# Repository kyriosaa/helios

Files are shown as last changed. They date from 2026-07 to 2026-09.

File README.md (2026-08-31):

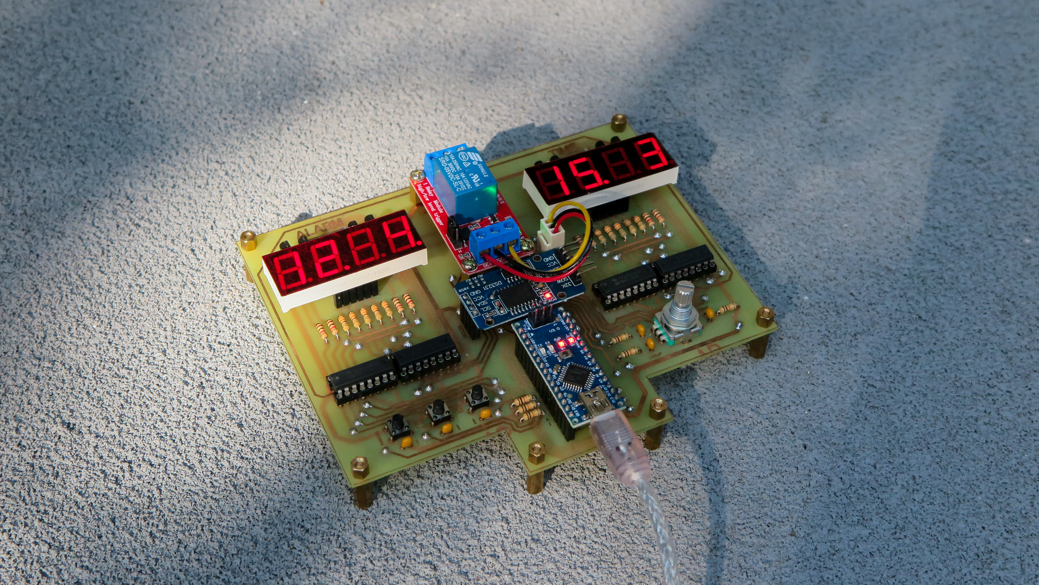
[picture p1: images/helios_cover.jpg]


# Helios


[]()



A real-time lamp controller for my room. Keeps the time (even when unplugged) and flips a relay once the clock and alarm values match. 

My room doesn't have windows so I created this device to automatically turn on my bedside lamp and put myself into fight or flight every morning to help me wake up in time for work/school.

🎥 [Demo Video](https://youtu.be/W-aWS8Oxe-Q?si=ozM3OOpzgYfn5PJq) 🎥

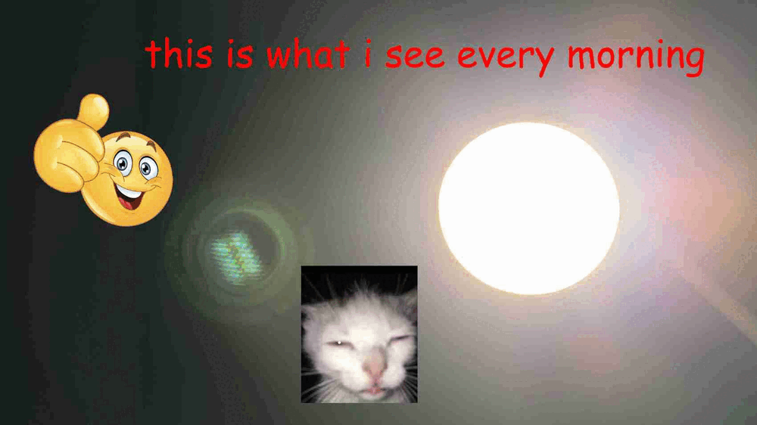
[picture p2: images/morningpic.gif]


| Sections |
| -------- |
| [Design](#design) |
| [Features](#features) |
| [Hardware](#hardware) |
| [PCB Design](#pcb-design) |
| [Schematic](#schematic) |
| [Images](#images) |

## Design

Some notes on why the board is built the way it is.

### A DS3231 instead of the MCU's own timer
The RTC has its own coin-cell backup, so the clock survives a power outage or being moved to another room. Keeping time on the MCU would mean re-setting the clock every time the device lost power, which is exactly the kind of small annoyance that would make me stop using it.

---

### Discrete multiplexing over a dedicated driver
A MAX7219 or TM1637 would have done this with fewer parts and less code. I used two 74HC595s for the segments and a 74HC138 plus PNP high-side drivers per display because I to practice building the multiplexing myself instead of buying it in a chip.

---

### A polled encoder, not an interrupt 
Every input has a 10k resistor and a 100nF capacitor on it to filter out switch bounce. The tradeoff to this is that signals now fade between HIGH and LOW over about a millisecond instead of snapping. During that fade, the Arduino can't really tell which one it's looking at, so a little noise makes it read HIGH-LOW-HIGH-LOW a few times before settling. An interrupt on `ENC_CLK` (D2) would count every one of those HIGH-LOW flips, so one click of the encoder knob would add 3 or 4 counts. However, reading the pin in the `loop()` function only ever sees the value after it settles, which solves the issue.

---

### Two board versions 
The 2-layer version is meant to be manually etched. But I know most people dont have an etching machine, so the 4-layer version is for anyone who doesn't have an etching setup and would rather send it to a manufacturer (I'm also experimenting with curved traces on the 4-layer version).

## Features

| Feature | Description |
| --- | --- |
| **24/7 Timekeeping** | A coin battery supports the DS3231, so pulling the plug doesn't require a manual time recalibration |
| **Dual Displays** | Separate 7-segment displays for the current time and alarm |
| **Manual Override** | One button forces the lamp on and disarms the alarm. The armed state is shown by a decimal point on the alarm display |
| **System ON/OFF** | Pressing the encoder blanks the displays and cuts the relay |
| **Multiplexed Digits** | Two 74HC595s (daisy-chained) drive segments, 74HC138s + PNP high-side drivers select digits |

## Hardware

| Ref | Qty | Part | Role |
| --- | --- | --- | --- |
| **A1** | 1 | Arduino Nano v3.x | MCU, socketed so it can be swapped without desoldering |
| **U1, U4** | 2 | 74HC595 | Daisy-chained shift registers driving the segment lines |
| **U2, U5** | 2 | 74HC138 | 3-to-8 decoders selecting which digit is lit |
| **U3, U6** | 2 | CA56-12EWA | Common-anode 4-digit 7-segment displays (time and alarm) |
| **Q1–Q8** | 8 | BC557 (PNP) | High-side drivers sourcing current into the selected digit |
| **SW1** | 1 | ALPS EC11E rotary encoder w/ switch | Sets values; pressing it toggles the system on/off |
| **SW2–SW4** | 3 | 6mm tactile push button | Mode, set, and manual lamp override |
| **J1** | 1 | JST-XH 1x03 | Relay / lamp output |
| **J2** | 1 | 1x04 pin socket | DS3231 RTC module (VCC, GND, SDA, SCL) |
| **R1–R6** | 6 | 10k | Pull-ups on the encoder and buttons |
| **R7–R10, R27–R30** | 8 | 1k | Base resistors for the PNP digit drivers |
| **R11–R26** | 16 | 330 | Segment current limiting |
| **C1–C8** | 8 | 100nF | Debounce caps on the inputs, paired with the 10k pull-ups |

Full parts list: [helios_bom.csv](./2layer/documents/helios_bom.csv)

## PCB Design

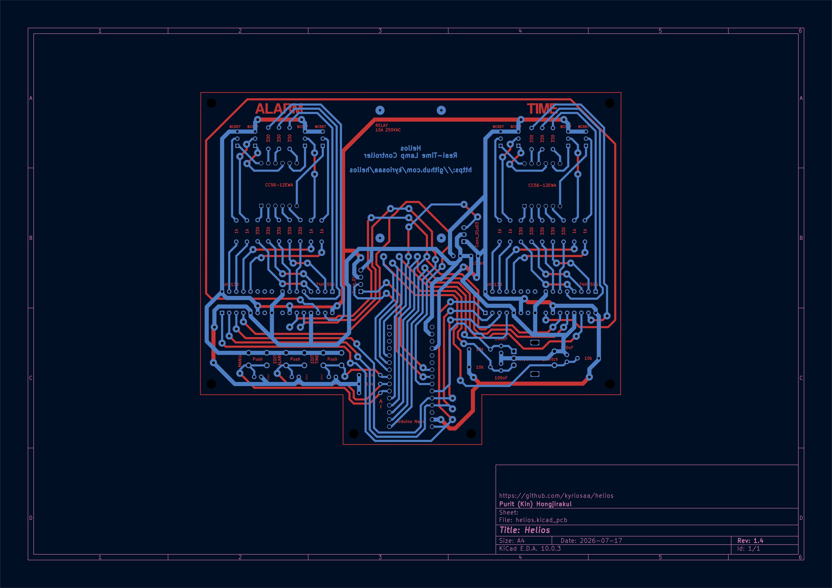
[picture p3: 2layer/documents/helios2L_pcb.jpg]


## Schematic








## Images


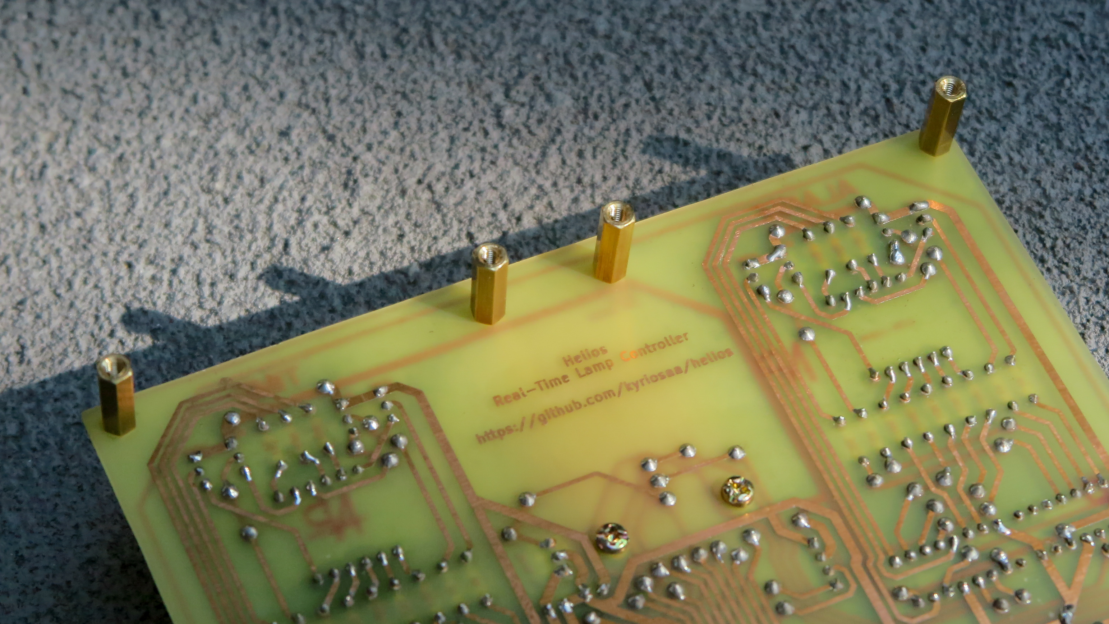
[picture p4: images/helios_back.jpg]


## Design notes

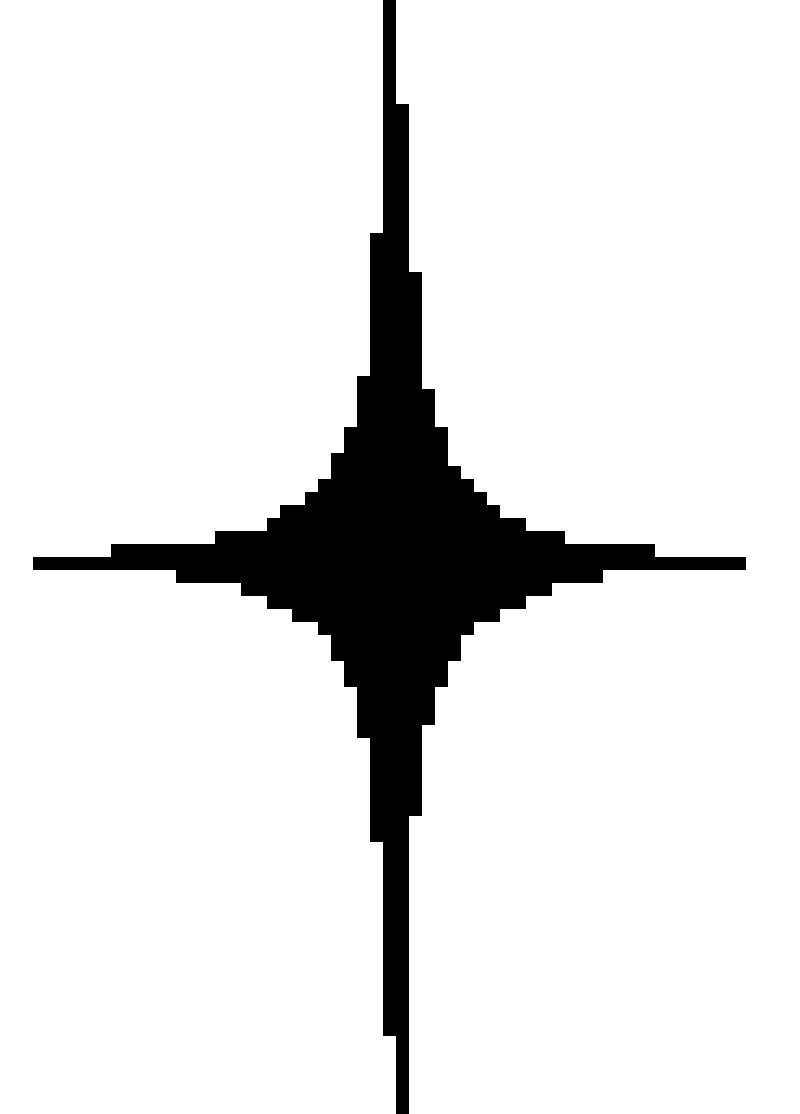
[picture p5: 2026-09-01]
4layer/assets/widestar.jpg

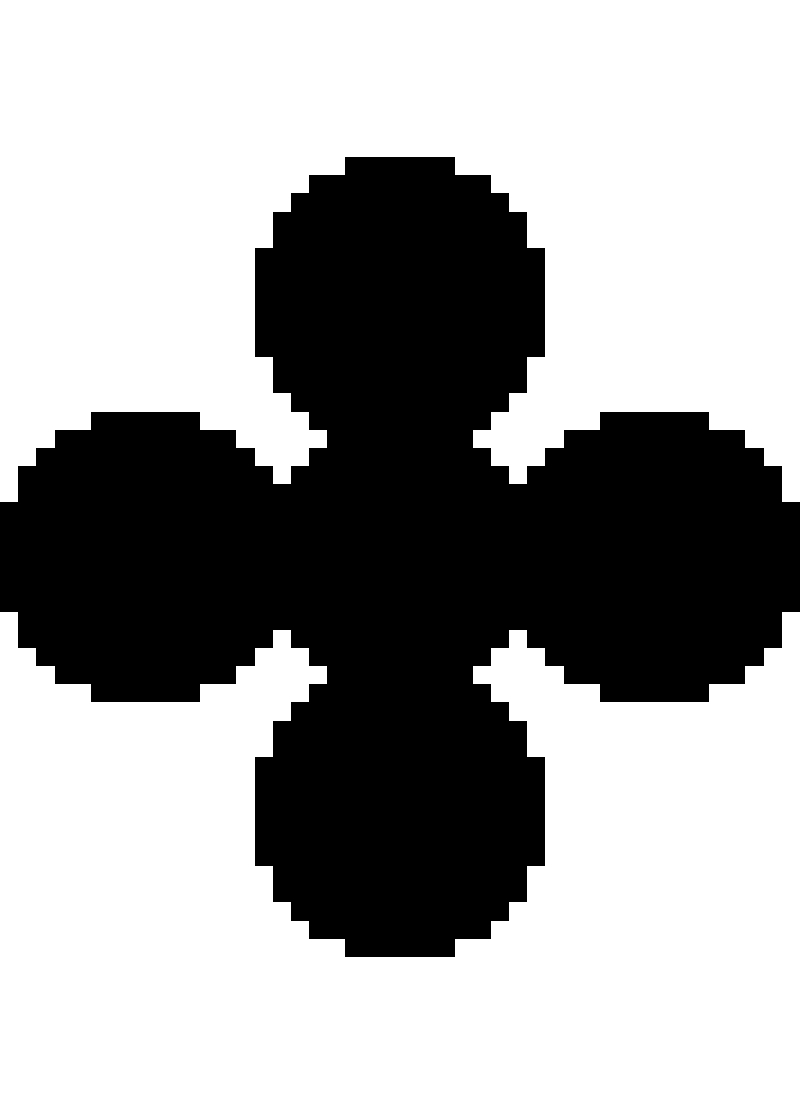
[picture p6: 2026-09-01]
4layer/assets/flower.jpg

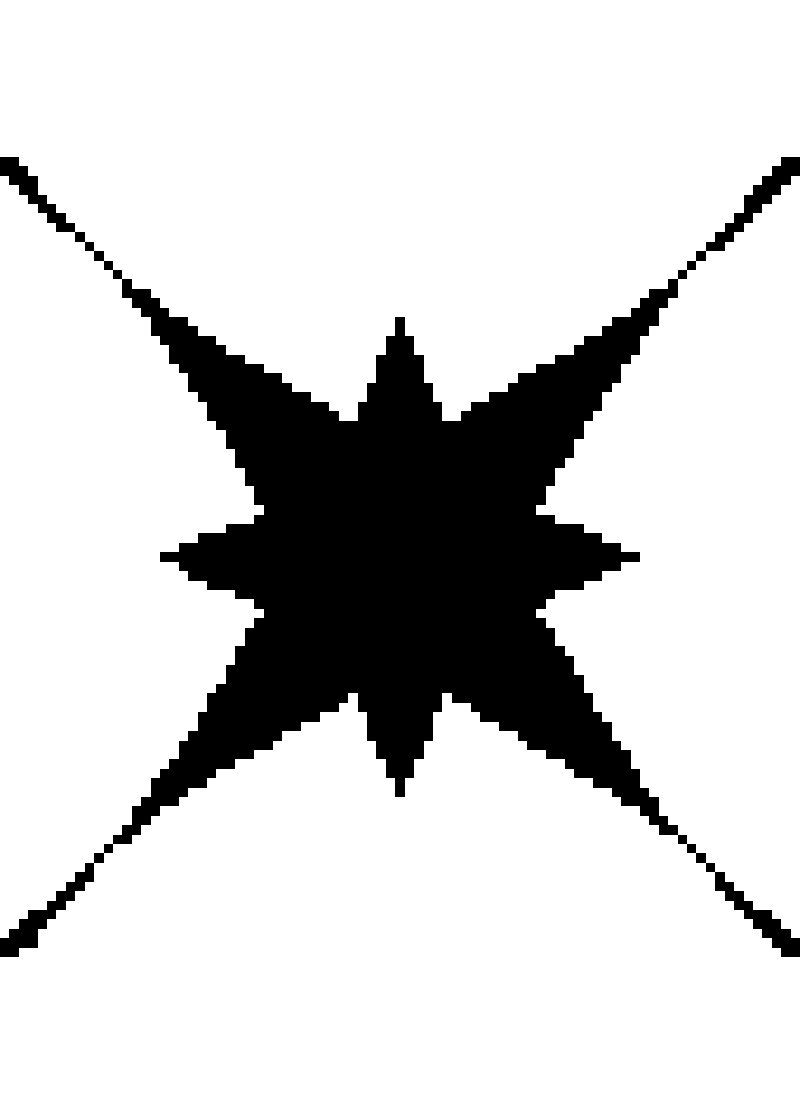
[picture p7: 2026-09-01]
4layer/assets/spikestar.jpg

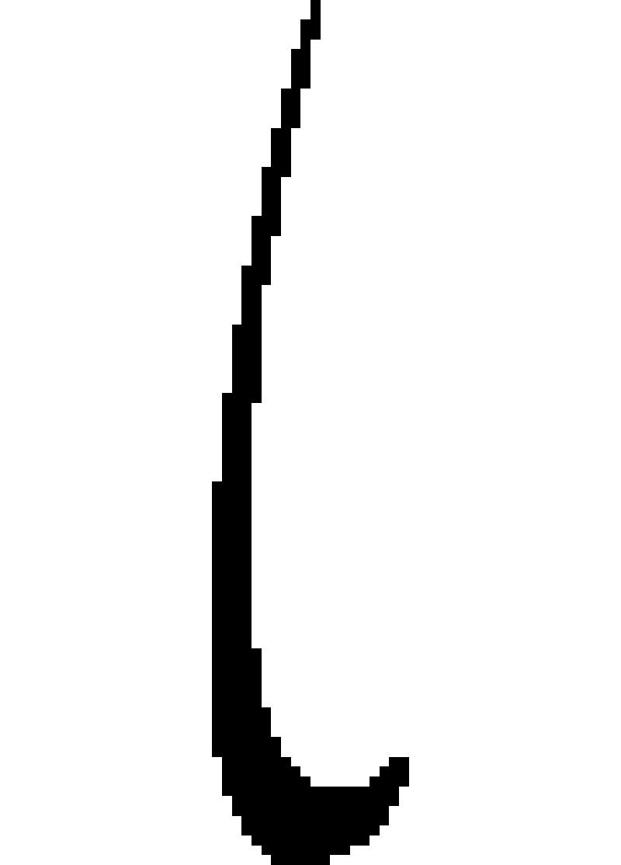
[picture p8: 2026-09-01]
4layer/assets/swoosh.jpg

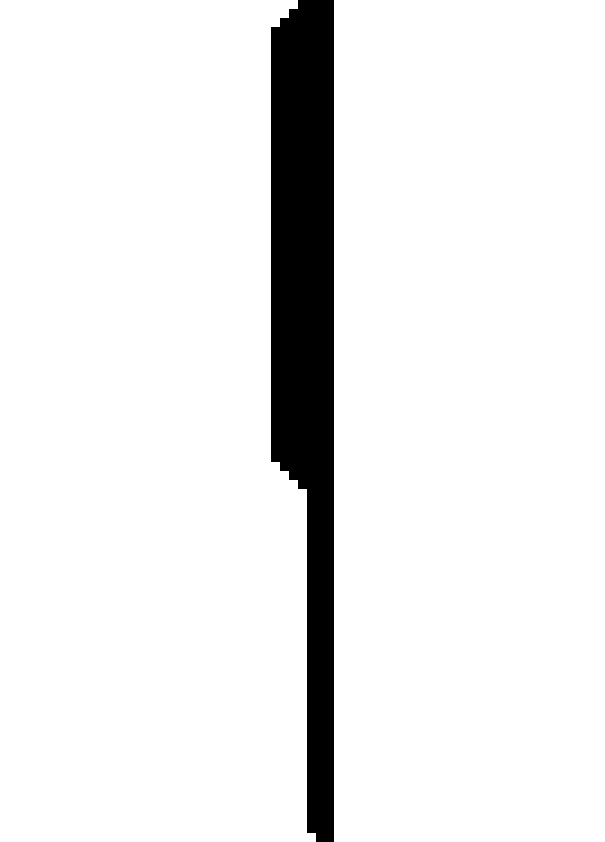
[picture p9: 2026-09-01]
4layer/assets/headertool.jpg

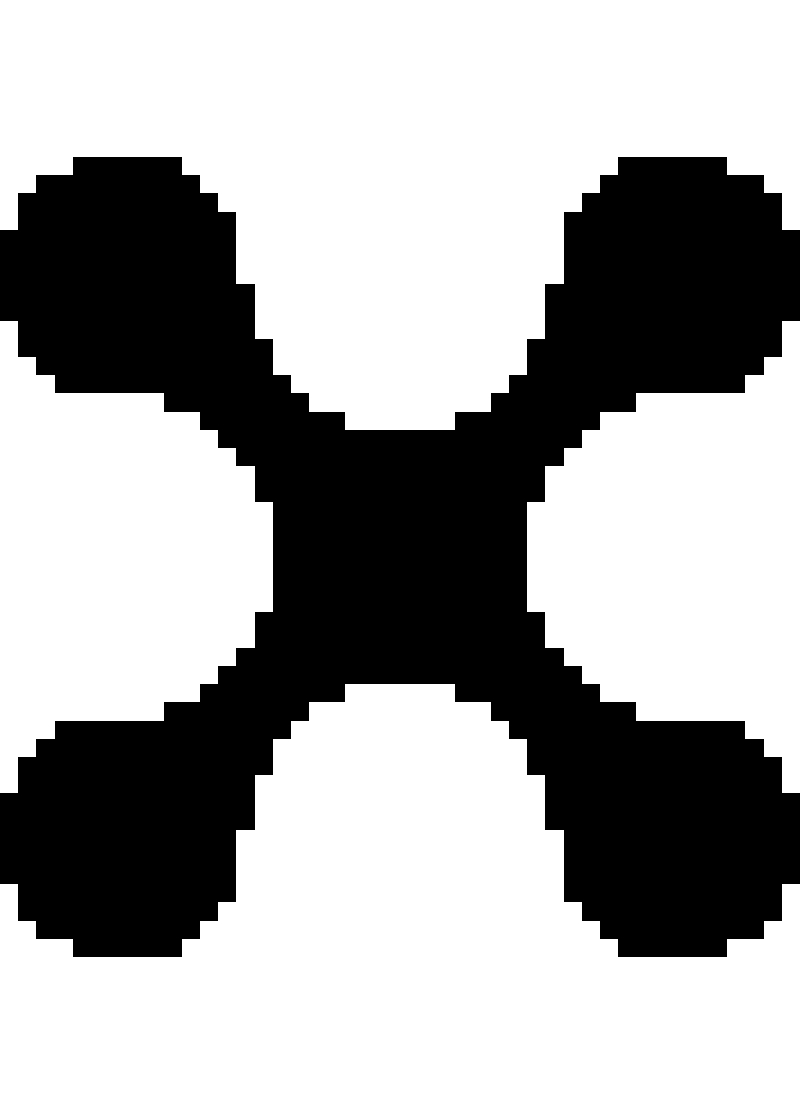
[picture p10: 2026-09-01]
4layer/assets/blooper.jpg

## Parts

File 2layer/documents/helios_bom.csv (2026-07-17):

Reference | Qty | Value | DNP | Exclude from BOM | Exclude from Board | Footprint | Datasheet
A1 | 1 | Arduino_Nano_v3.x |  |  |  | Module:Arduino_Nano | http://www.mouser.com/pdfdocs/Gravitech_Arduino_Nano3_0.pdf
C1,C2,C3,C4,C5,C6,C7,C8 | 8 | 100nF |  |  |  | Capacitor_THT:C_Disc_D5.0mm_W2.5mm_P2.50mm
J1 | 1 | Conn_01x03 |  |  |  | Connector_JST:JST_XH_B3B-XH-A_1x03_P2.50mm_Vertical
J2 | 1 | Conn_01x04 |  |  |  | Connector_PinSocket_2.54mm:PinSocket_1x04_P2.54mm_Vertical
Q1,Q2,Q3,Q4,Q5,Q6,Q7,Q8 | 8 | BC557 |  |  |  | Package_TO_SOT_THT:TO-92_Inline_Wide | https://www.onsemi.com/pub/Collateral/BC556BTA-D.pdf
R1,R2,R3,R4,R5,R6 | 6 | 10k |  |  |  | Resistor_THT:R_Axial_DIN0207_L6.3mm_D2.5mm_P7.62mm_Horizontal
R7,R8,R9,R10,R27,R28,R29,R30 | 8 | 1k |  |  |  | Resistor_THT:R_Axial_DIN0207_L6.3mm_D2.5mm_P7.62mm_Horizontal
R11,R12,R13,R14,R15,R16,R17,R18,R19,R20,R21,R22,R23,R24,R25,R26 | 16 | 330 |  |  |  | Resistor_THT:R_Axial_DIN0207_L6.3mm_D2.5mm_P7.62mm_Horizontal
SW1 | 1 | RotaryEncoder_Switch |  |  |  | Rotary_Encoder:RotaryEncoder_Alps_EC11E-Switch_Vertical_H20mm
SW2,SW3,SW4 | 3 | SW_Push |  |  |  | Button_Switch_THT:SW_PUSH_6mm
U1,U4 | 2 | 74HC595 |  |  |  | Package_DIP:DIP-16_W7.62mm | http://www.ti.com/lit/ds/symlink/sn74hc595.pdf
U2,U5 | 2 | 74HC138 |  |  |  | Package_DIP:DIP-16_W7.62mm | http://www.ti.com/lit/ds/symlink/cd74hc238.pdf
U3,U6 | 2 | CA56-12EWA |  |  |  | Display_7Segment:CA56-12EWA | http://www.kingbrightusa.com/images/catalog/SPEC/CA56-12EWA.pdf

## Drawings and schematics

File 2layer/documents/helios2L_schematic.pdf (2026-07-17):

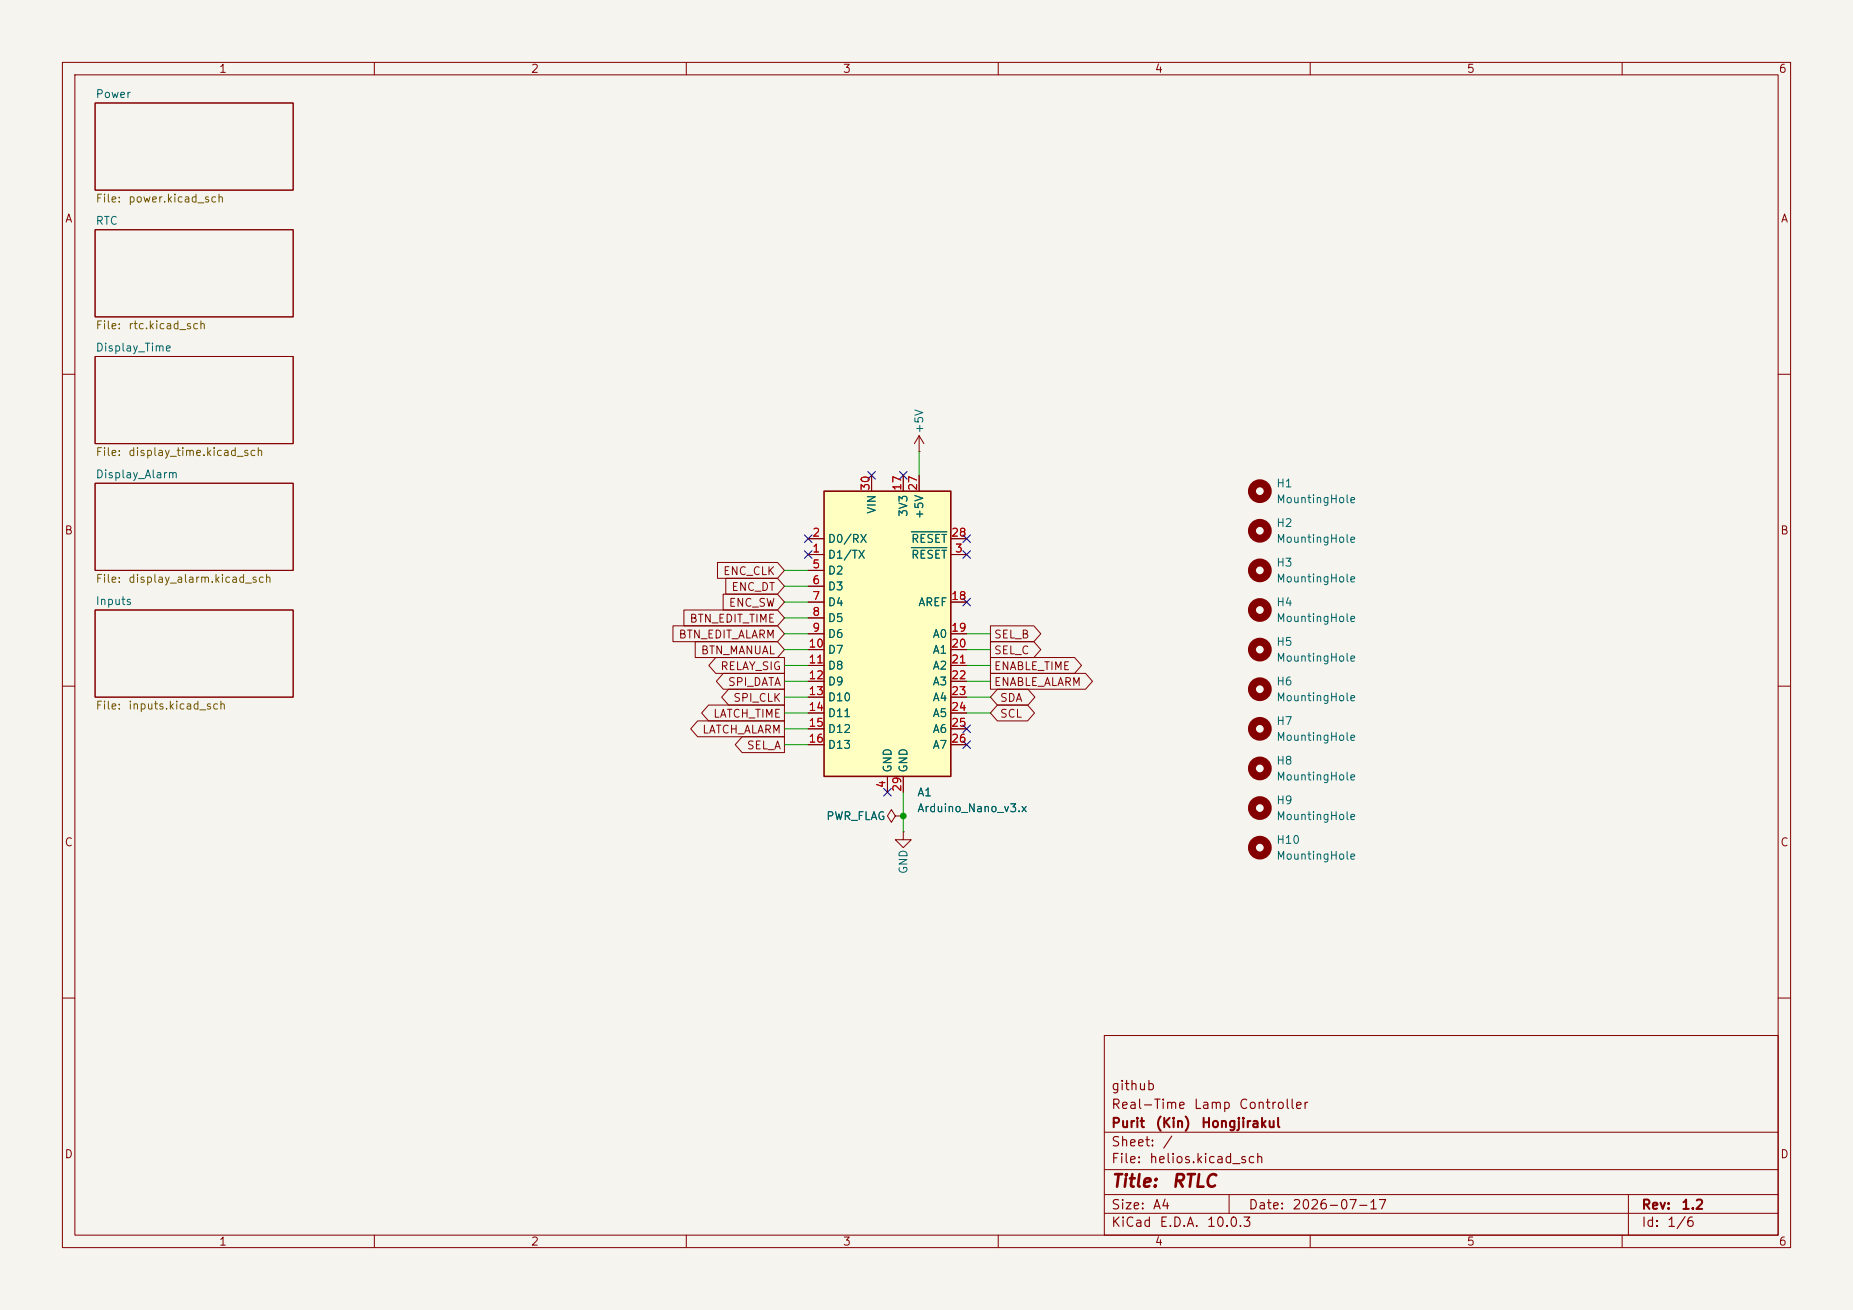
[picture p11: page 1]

Inputs File: inputs.kicad_sch RTC

File: rtc.kicad_sch Power File: power.kicad_sch

github
Real-Time Lamp Controller
Purit (Kin) Hongjirakul
Sheet: /
File: helios.kicad_sch
Title: RTLC

Size: A4 | Rev: 1.2
KiCad E.D.A. 10.0.3 | Id: 1/6

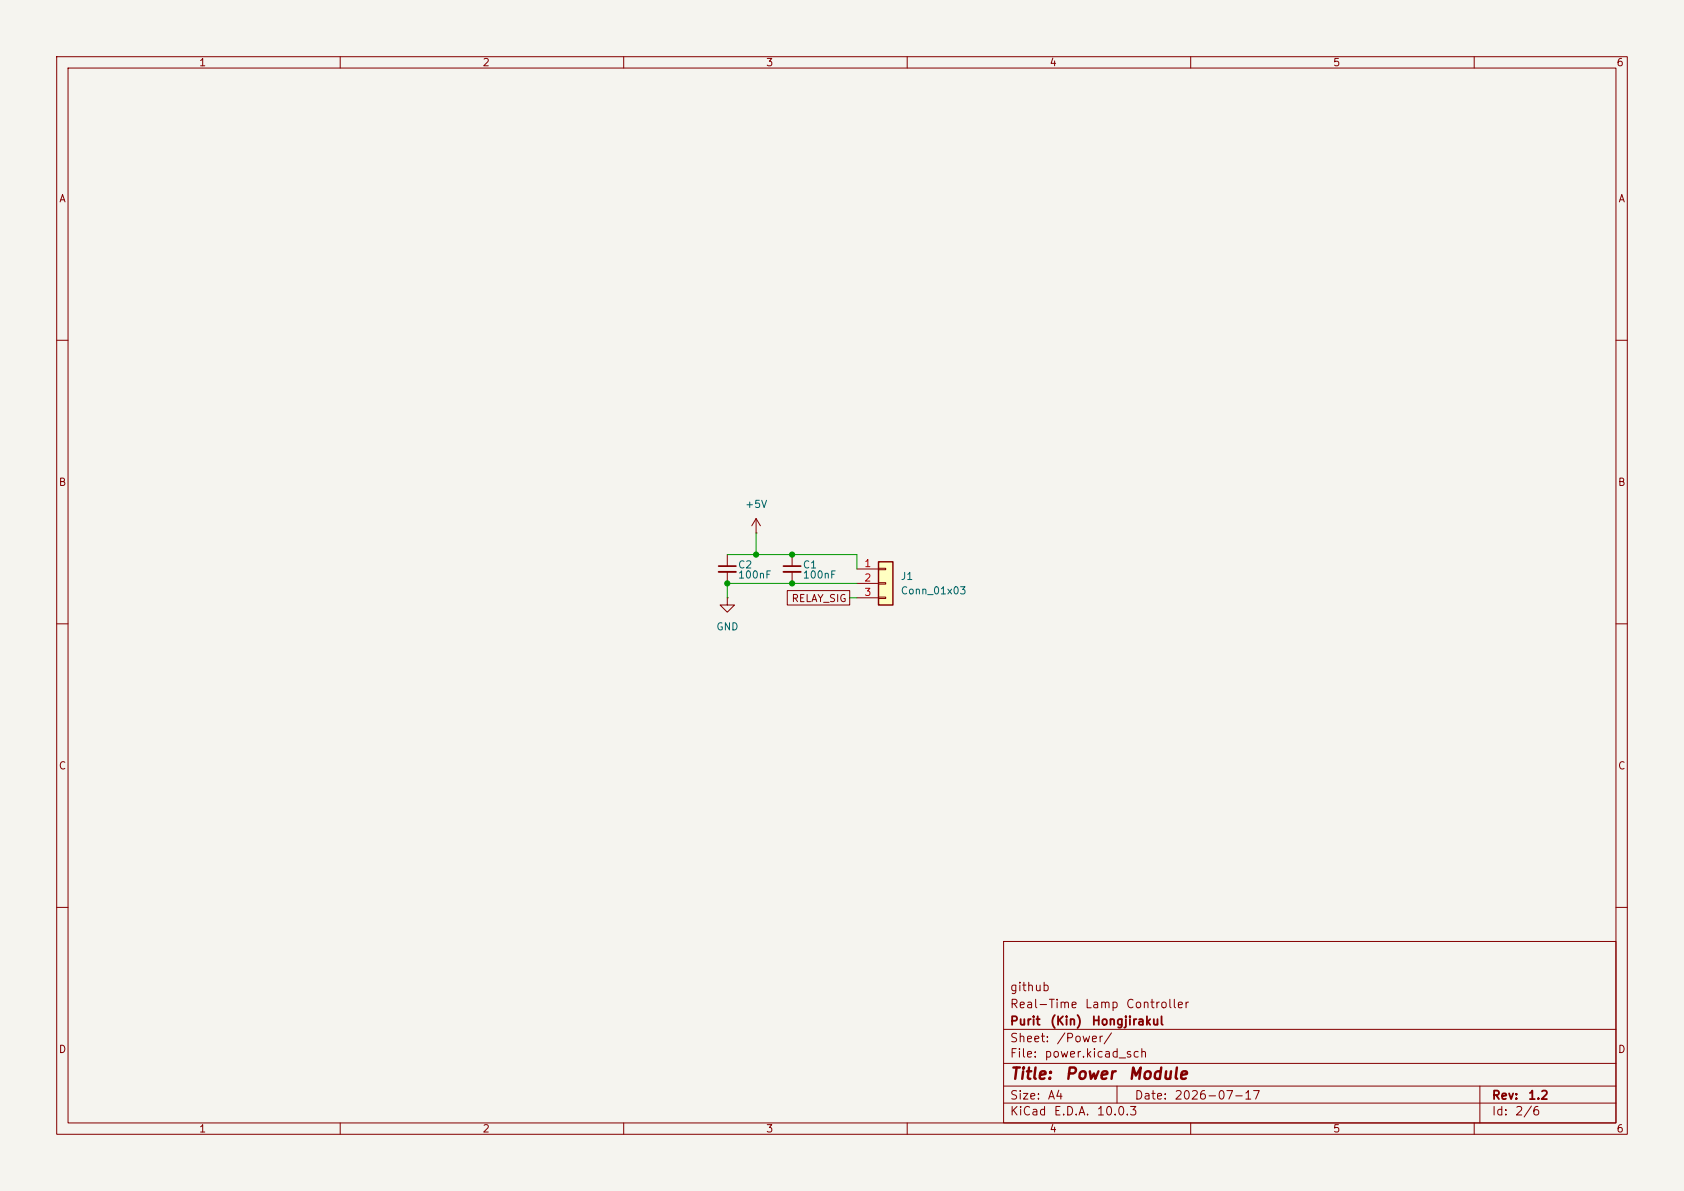
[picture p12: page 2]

Real-Time Lamp Controller
Purit (Kin) Hongjirakul
Sheet: /Power/
File: power.kicad_sch
Title: Power Module

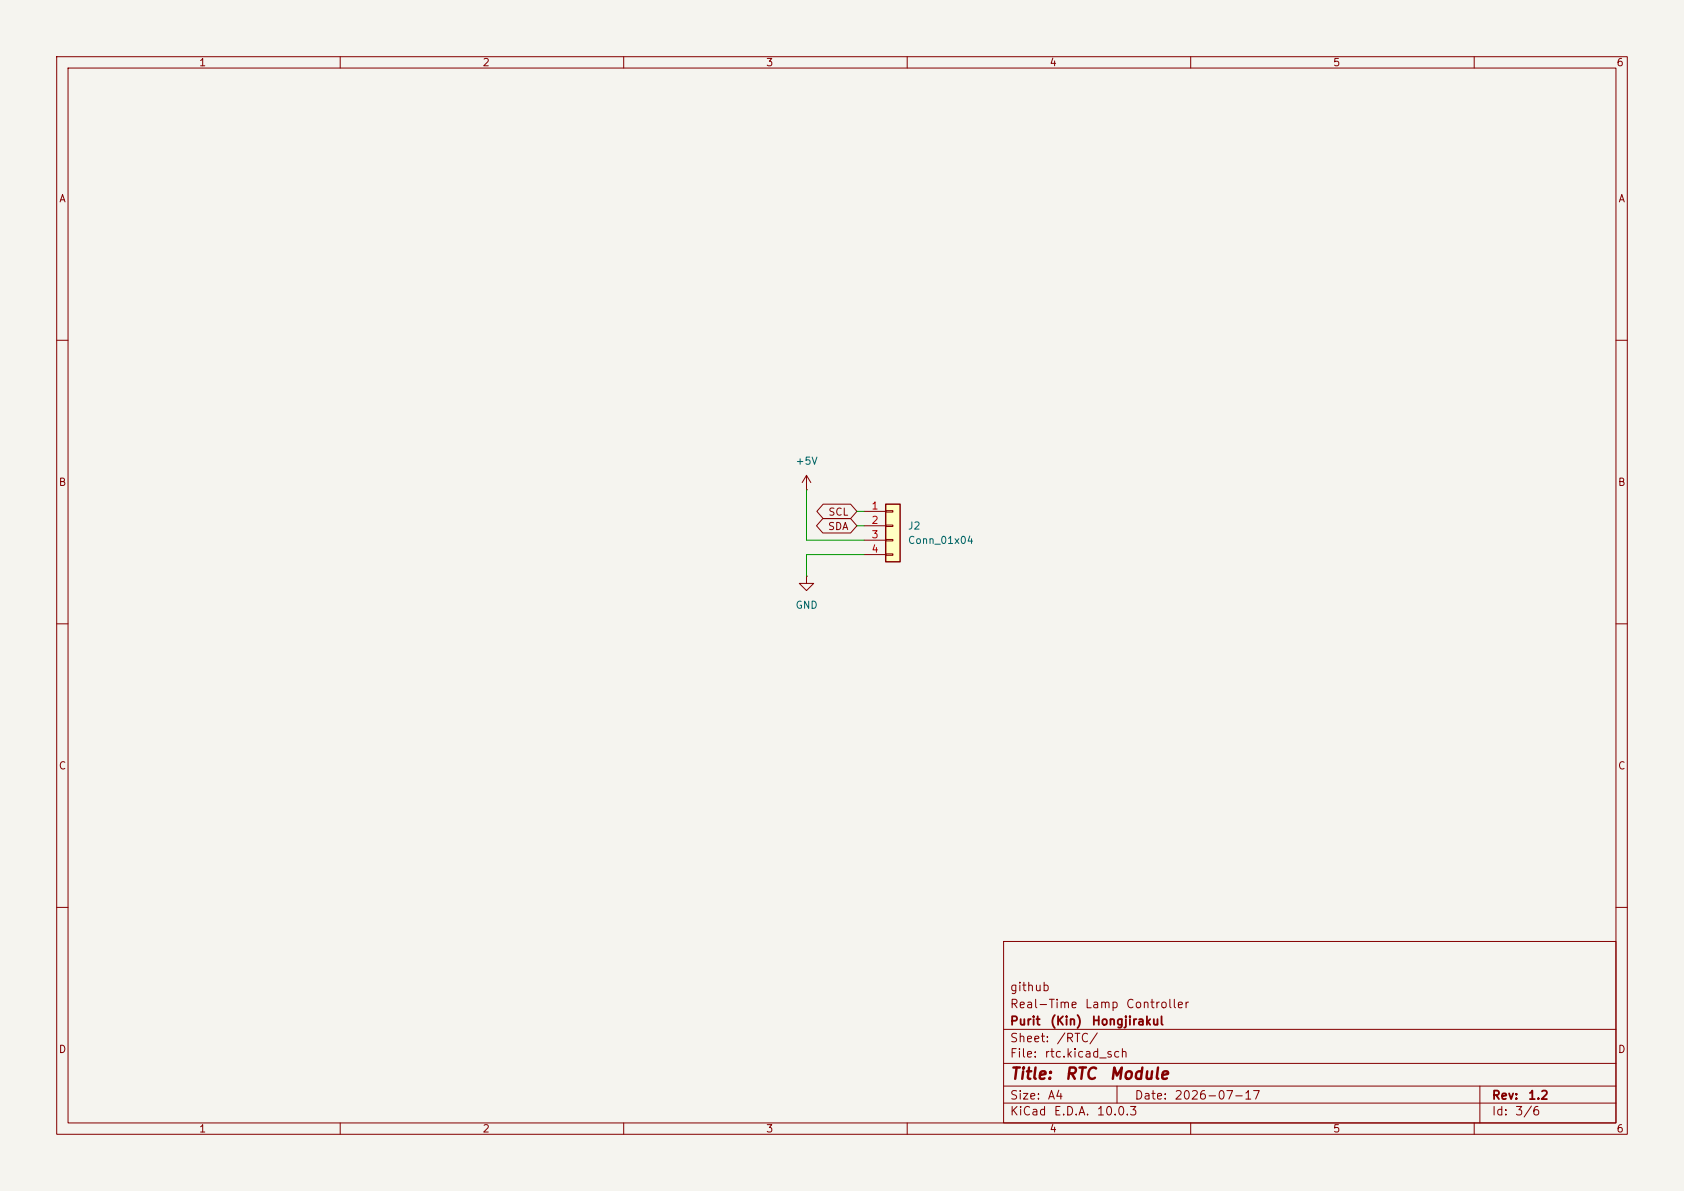
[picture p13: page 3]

Real-Time Lamp Controller
Purit (Kin) Hongjirakul
Sheet: /RTC/
File: rtc.kicad_sch
Title: RTC Module

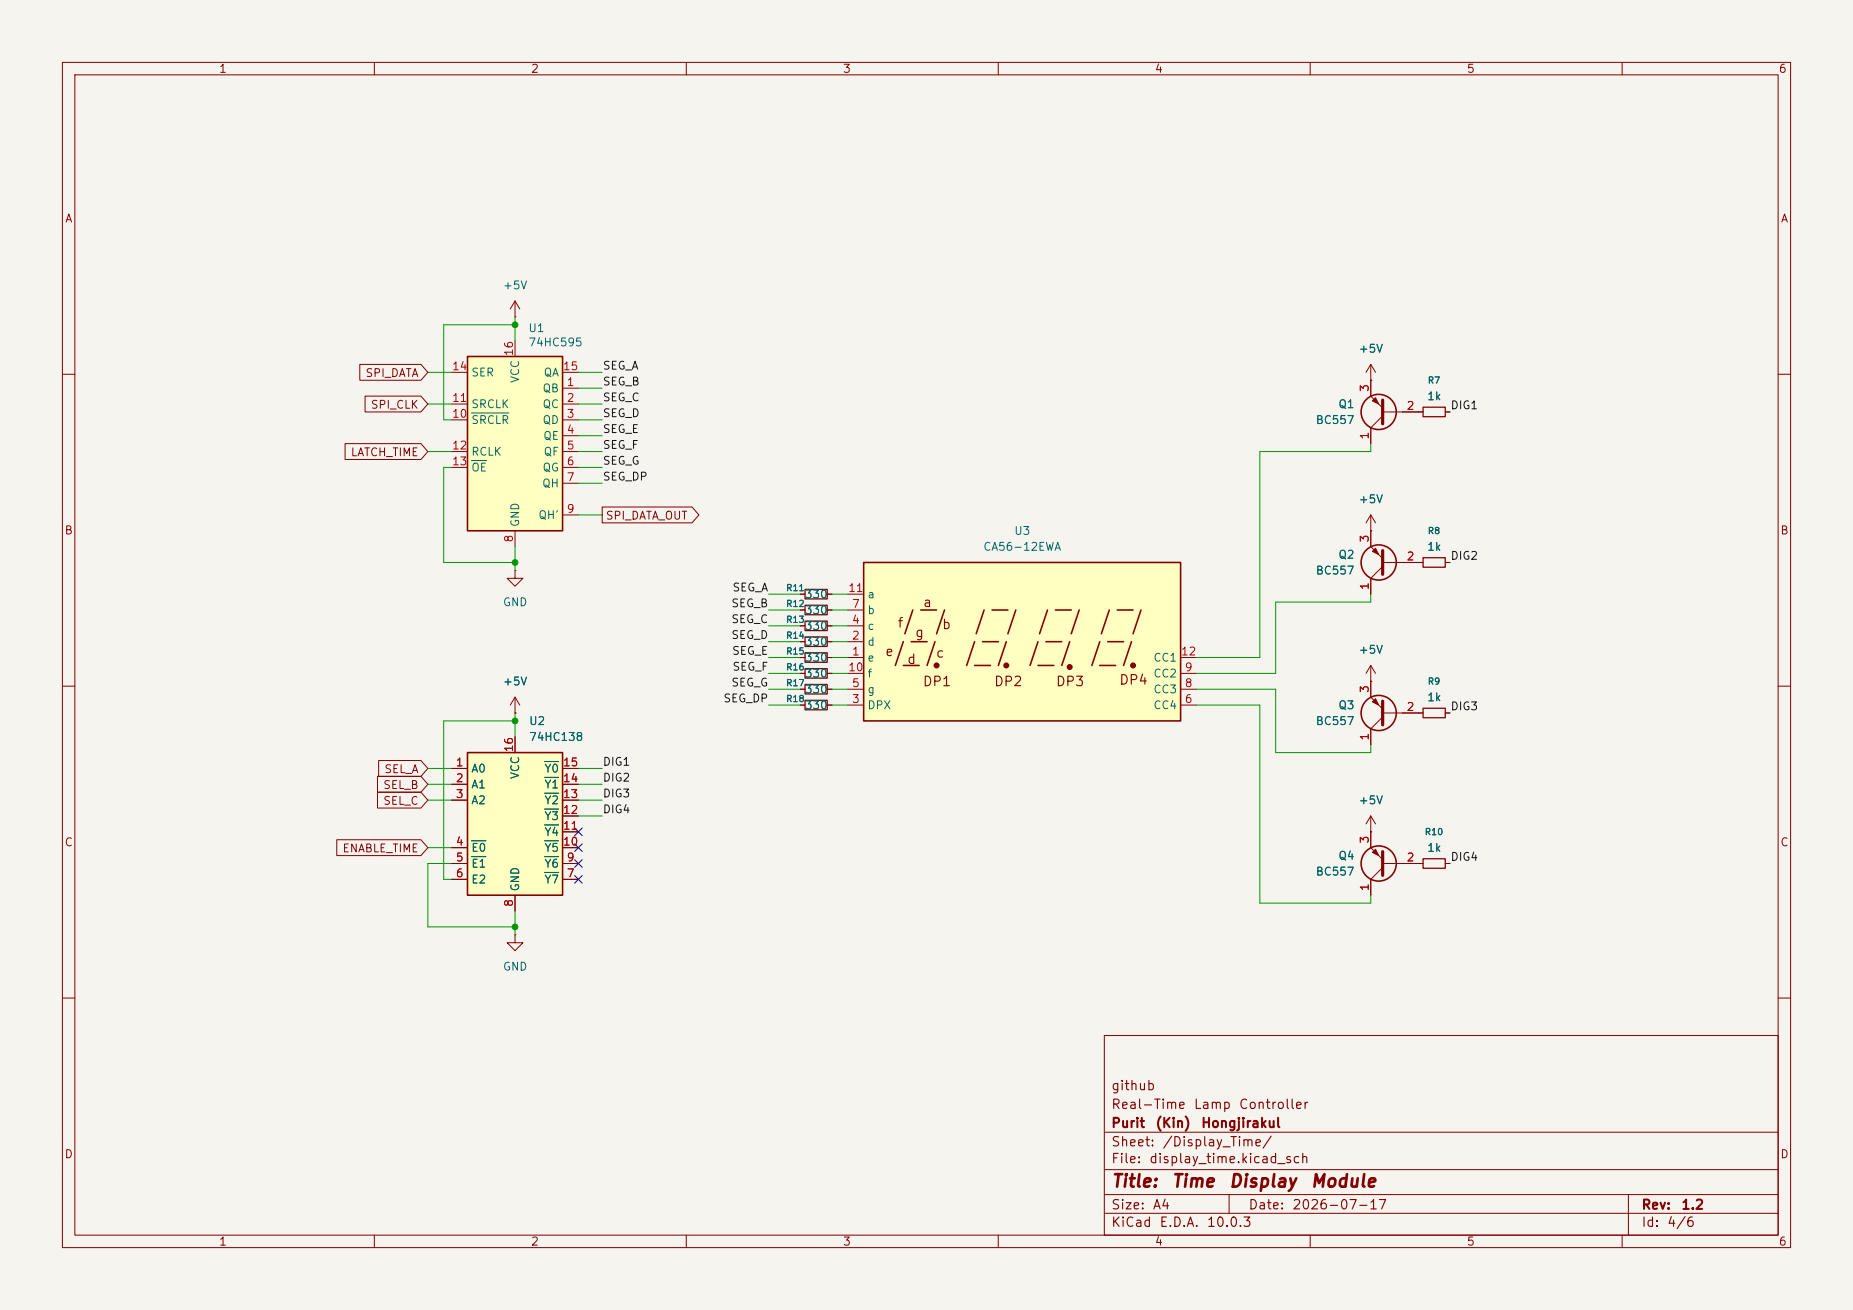
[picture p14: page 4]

SRCLR 10 SRCLK 11 RCLK 12 OE 13

E1 5
E2 6

github
Real-Time Lamp Controller
Purit (Kin) Hongjirakul
Sheet: /Display_Time/
File: display_time.kicad_sch
Title: Time Display Module

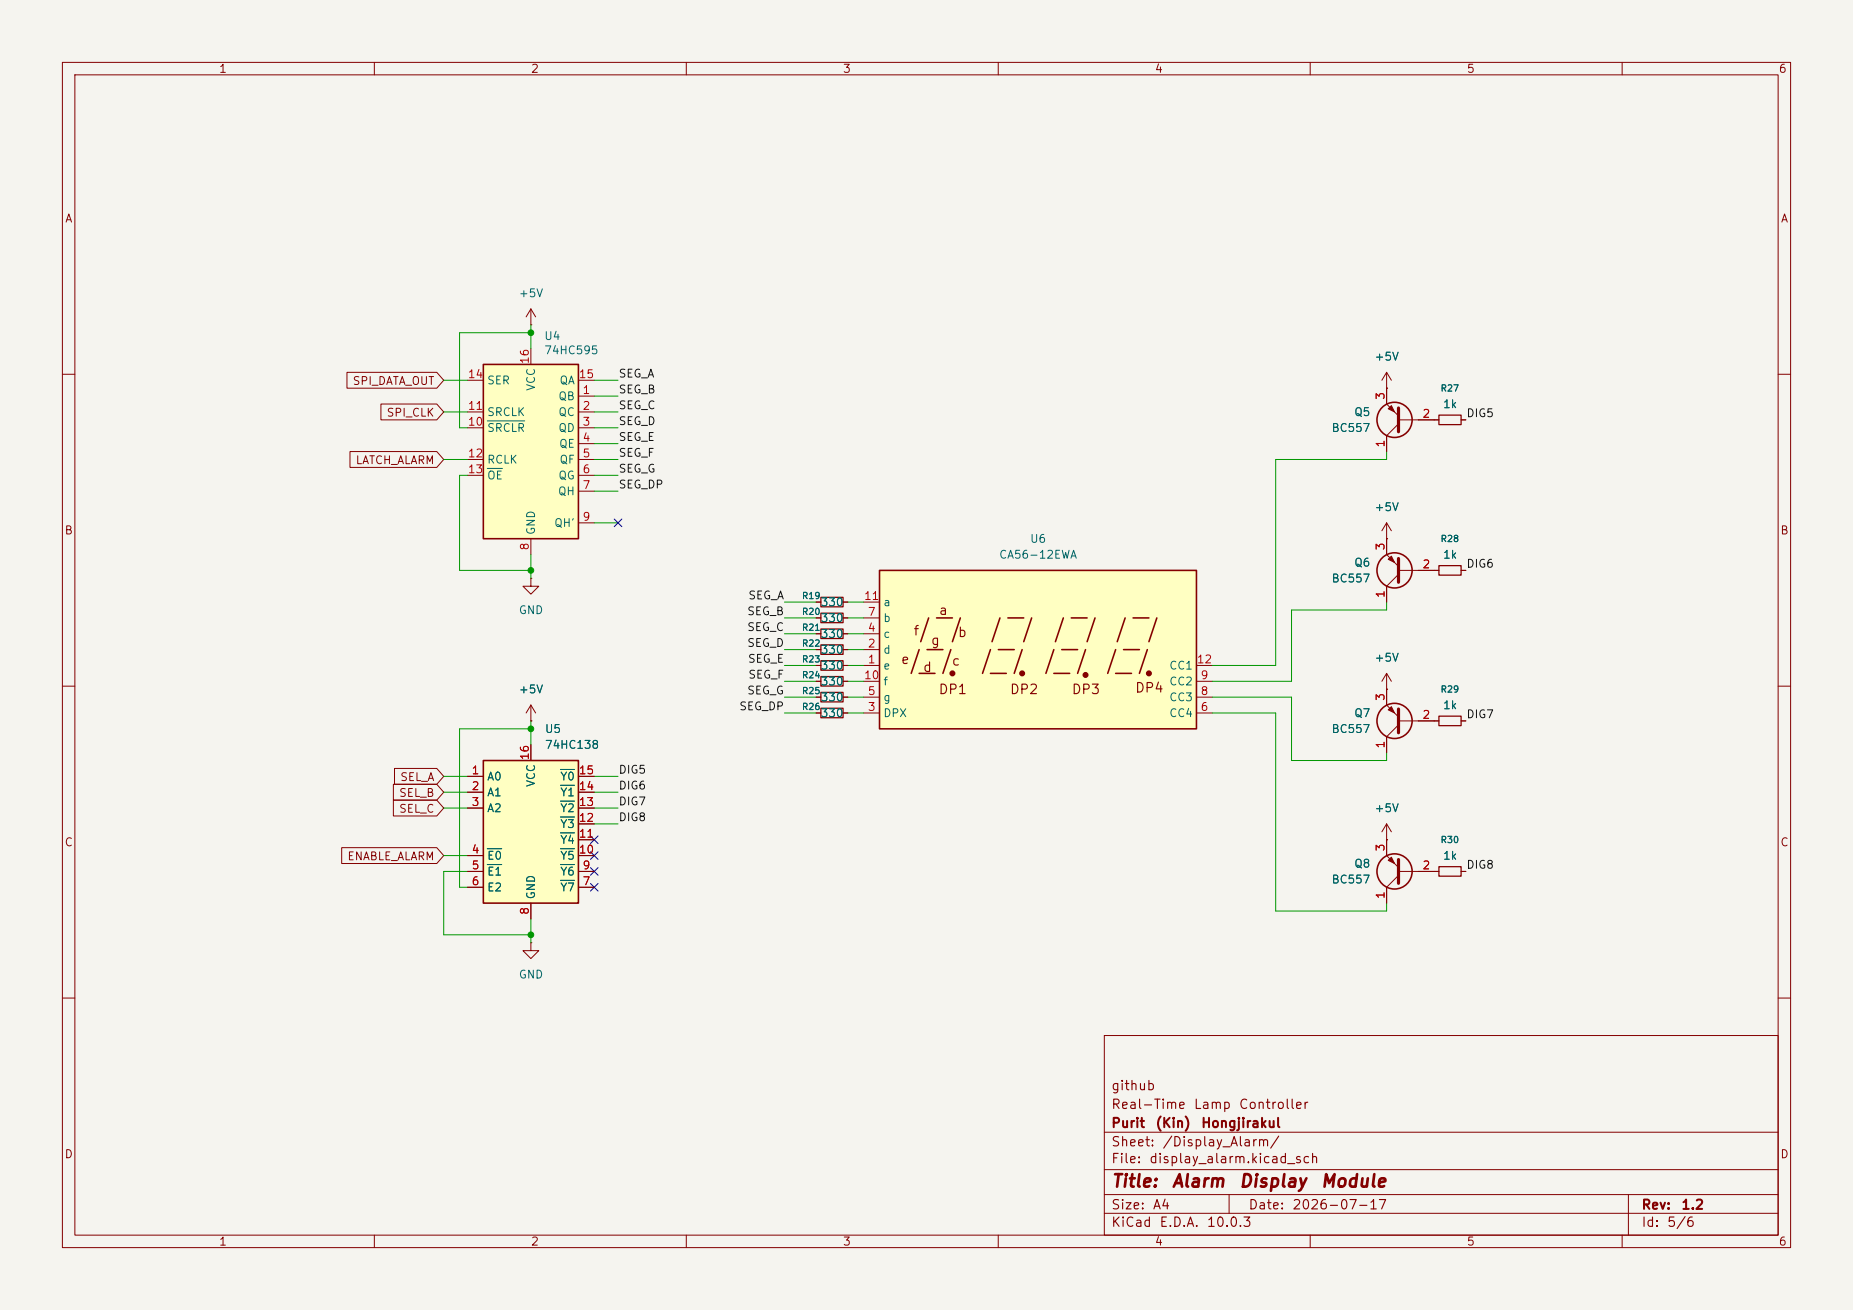
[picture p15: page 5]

SRCLR 10 SRCLK 11 RCLK 12 OE 13

E1 5
E2 6

github
Real-Time Lamp Controller
Purit (Kin) Hongjirakul
Sheet: /Display_Alarm/
File: display_alarm.kicad_sch
Title: Alarm Display Module

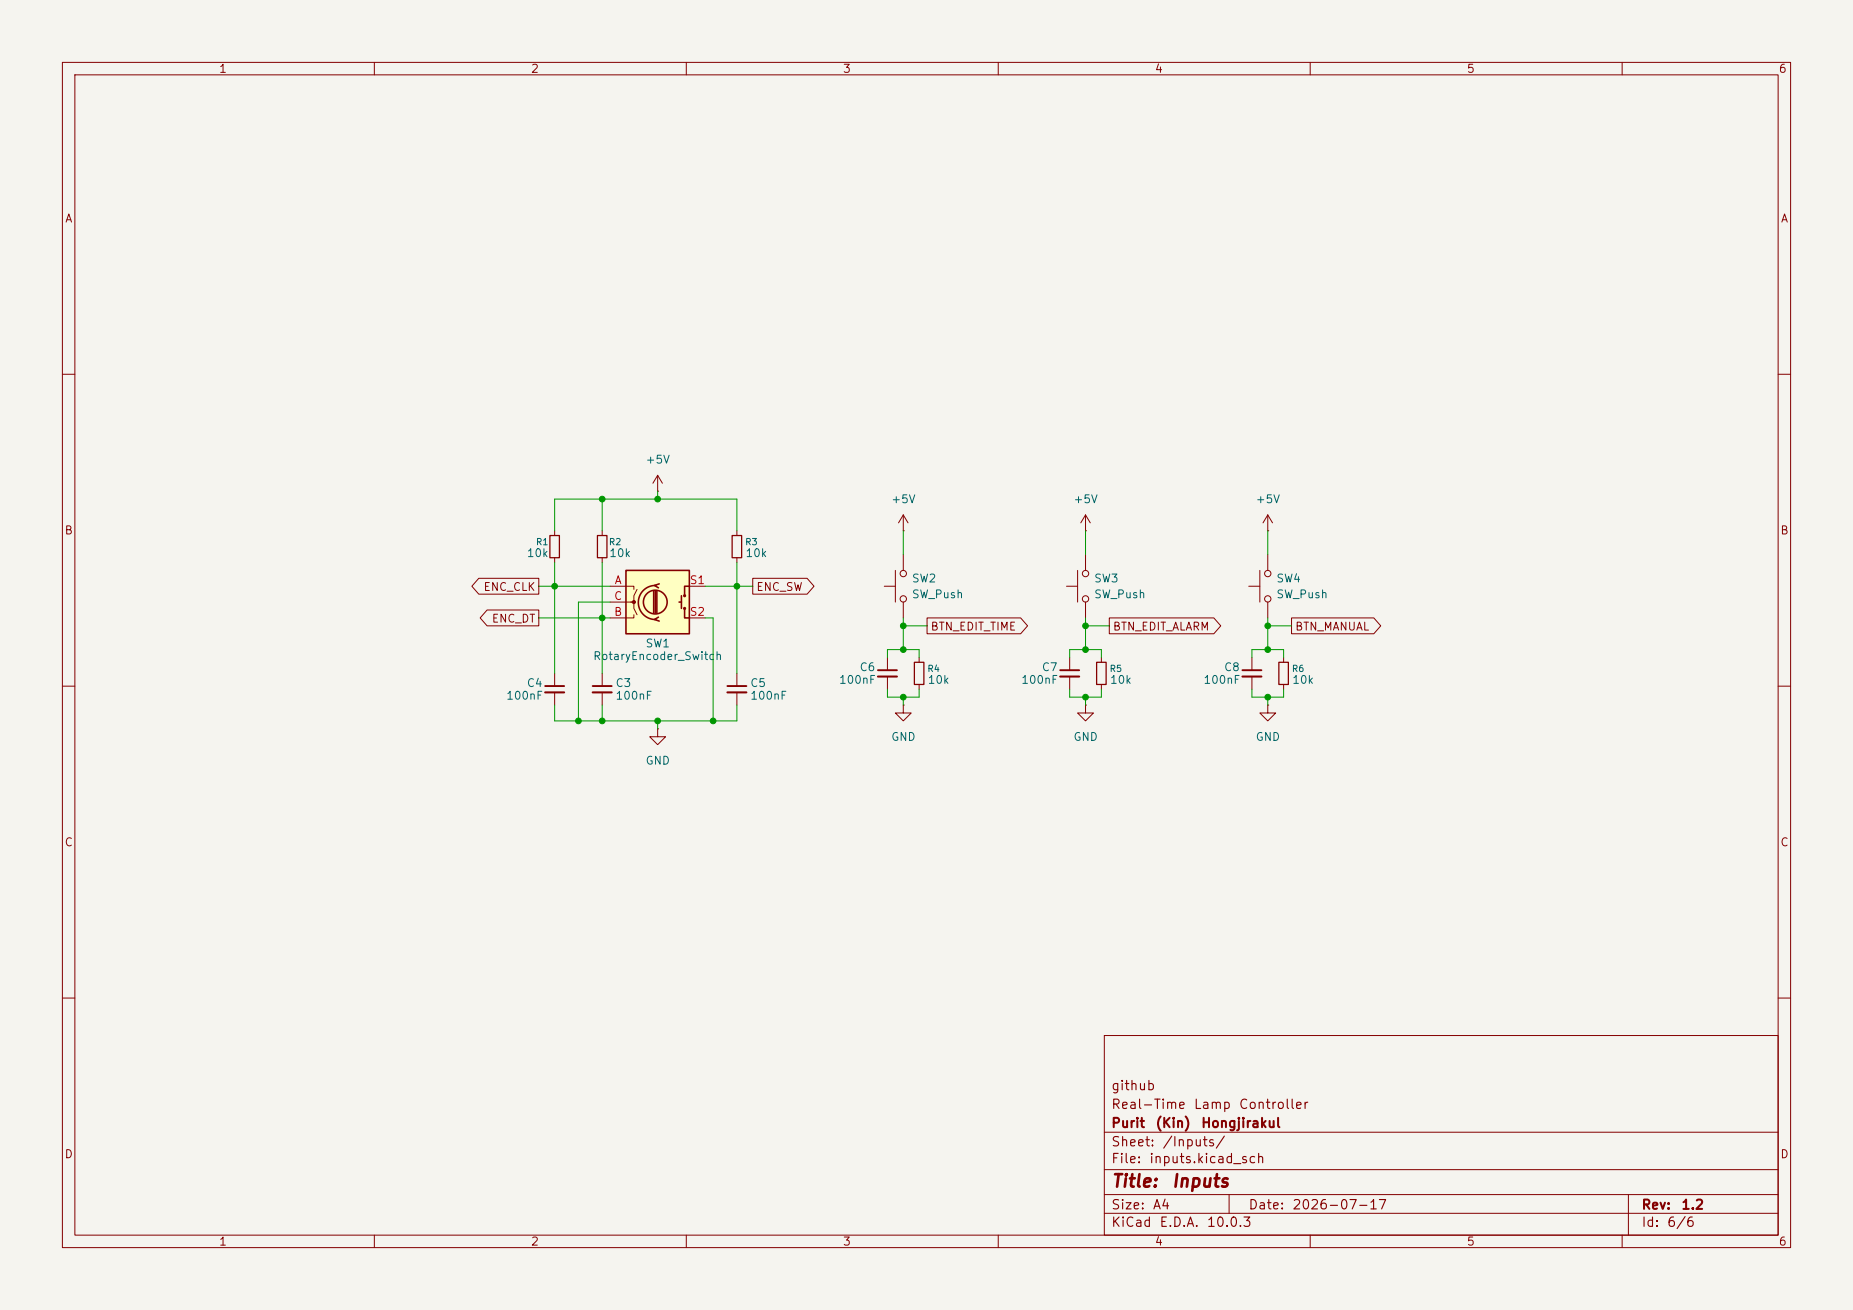
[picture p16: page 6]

Real-Time Lamp Controller
Purit (Kin) Hongjirakul
Sheet: /Inputs/
File: inputs.kicad_sch
Title: Inputs

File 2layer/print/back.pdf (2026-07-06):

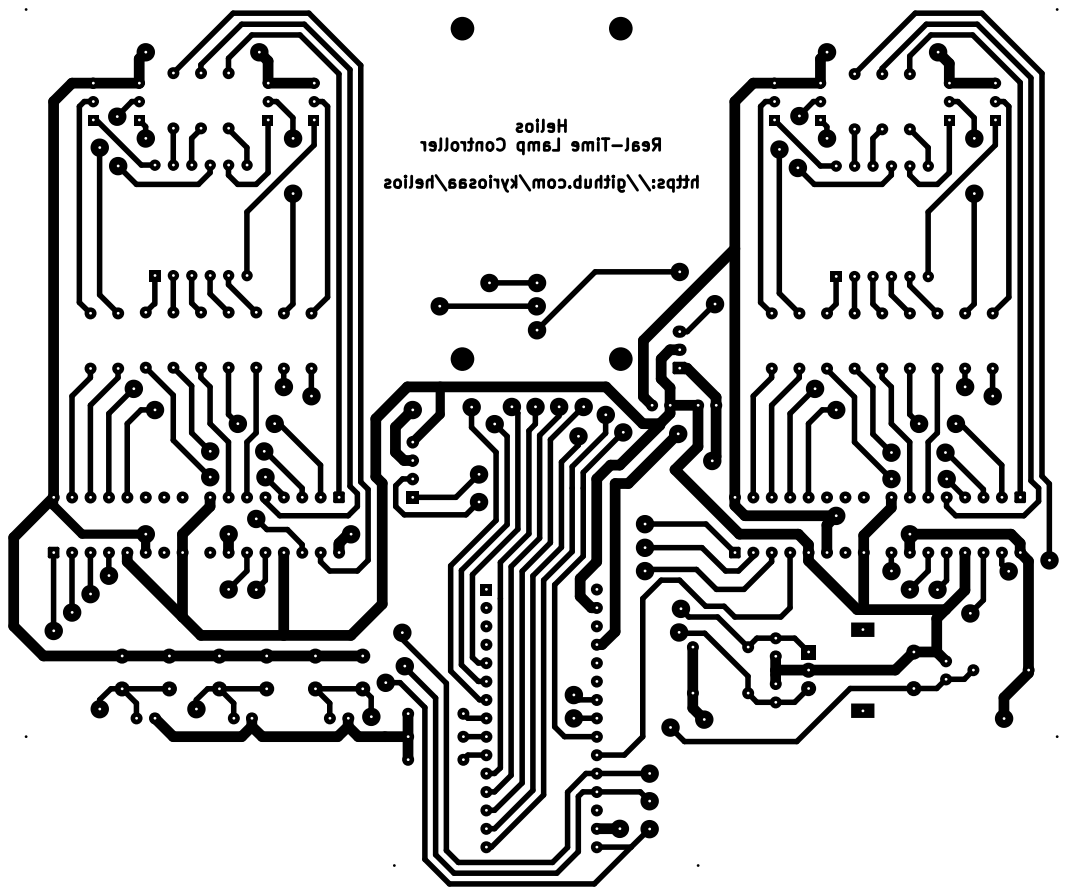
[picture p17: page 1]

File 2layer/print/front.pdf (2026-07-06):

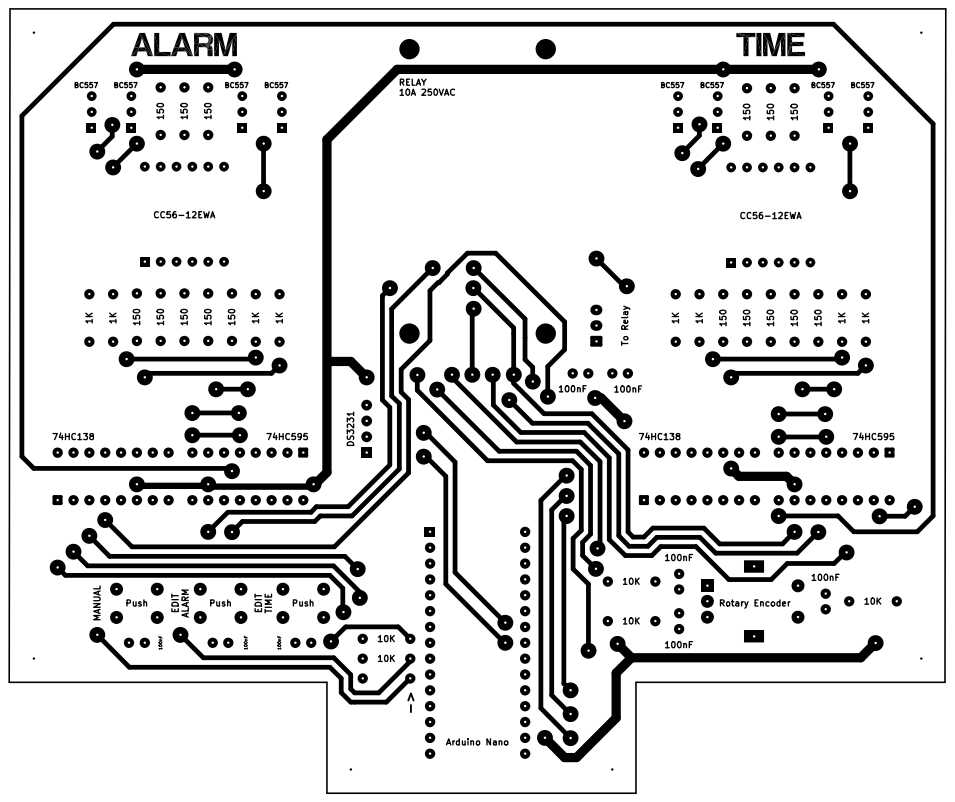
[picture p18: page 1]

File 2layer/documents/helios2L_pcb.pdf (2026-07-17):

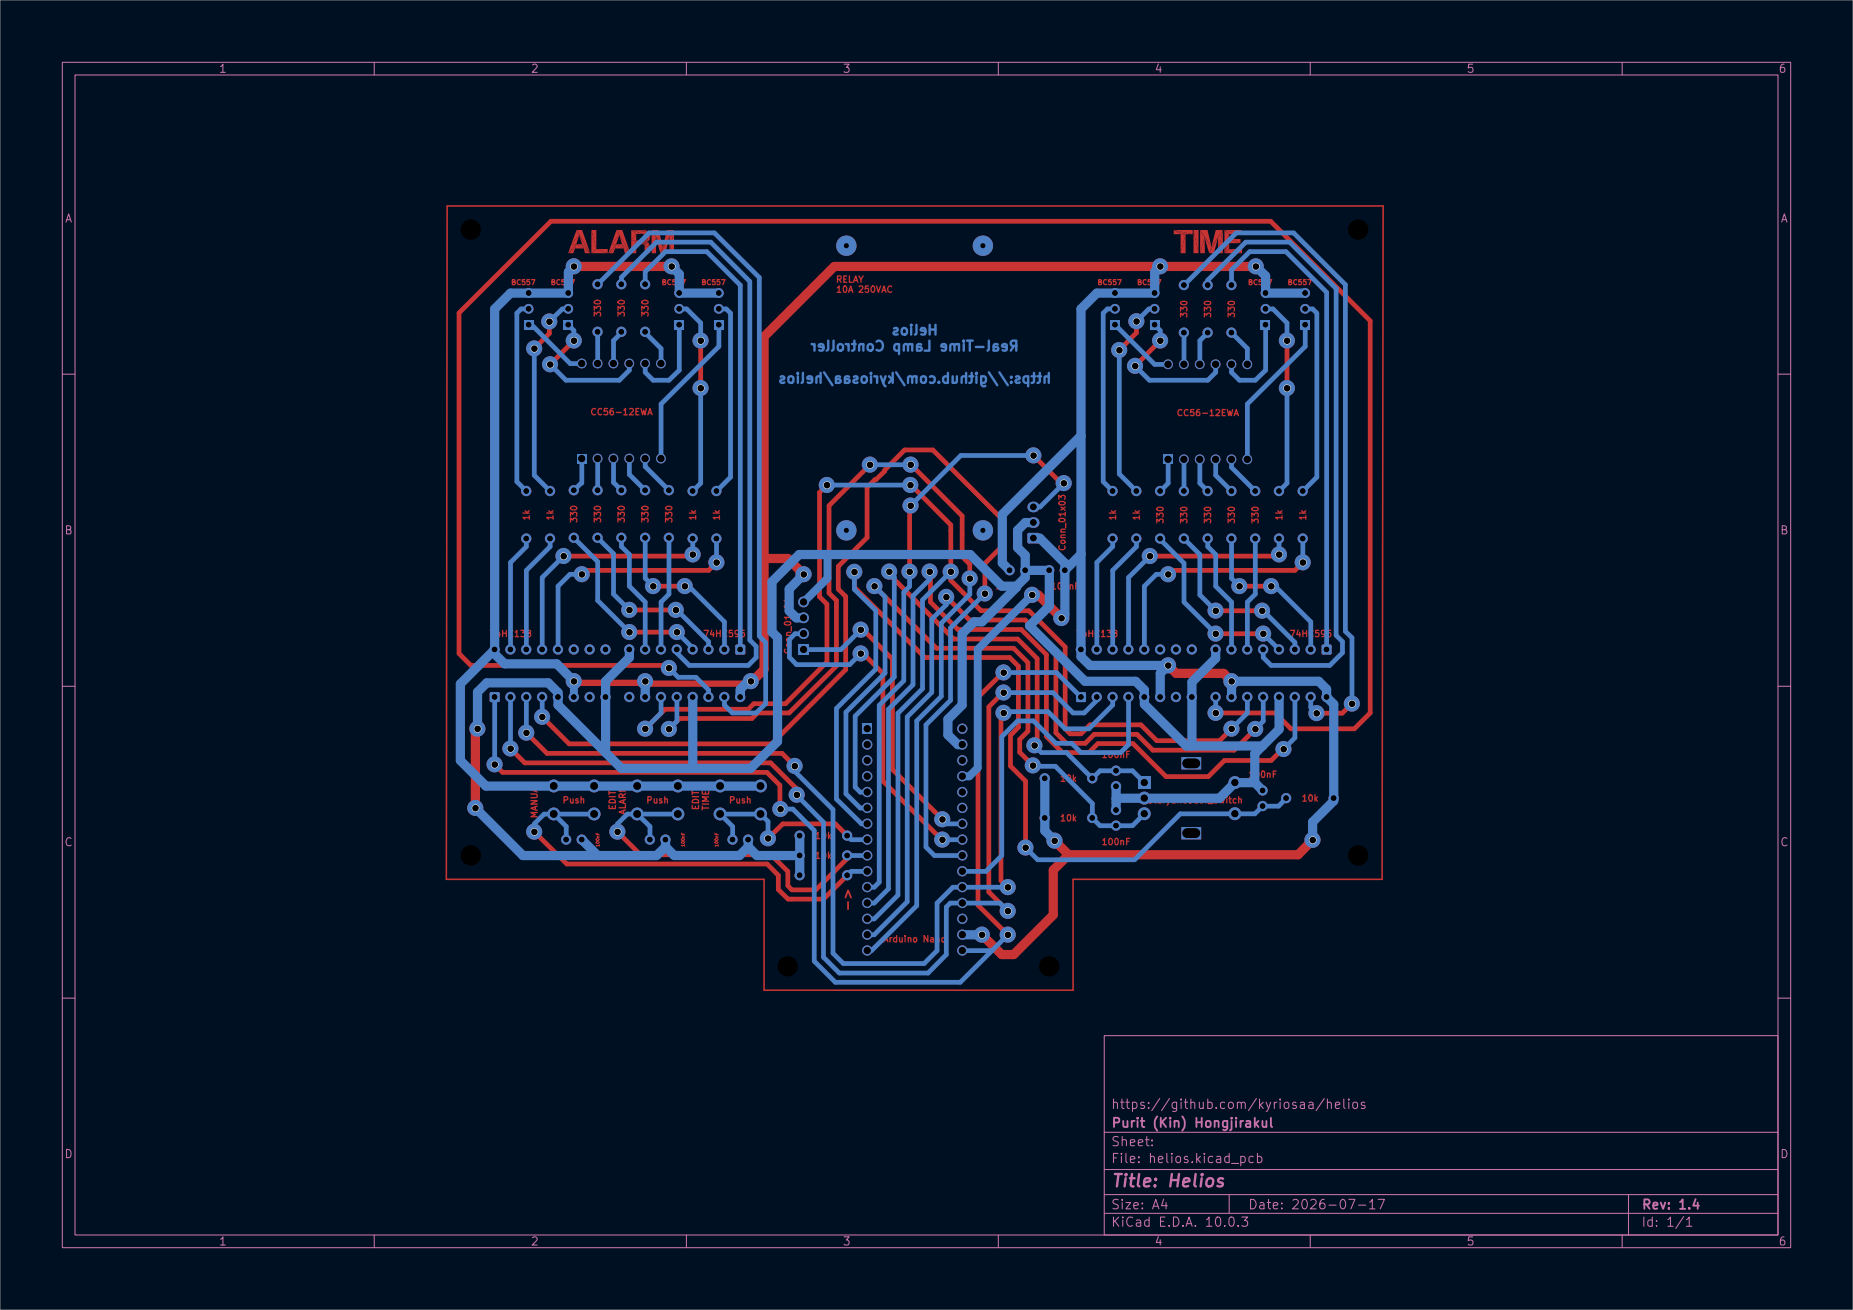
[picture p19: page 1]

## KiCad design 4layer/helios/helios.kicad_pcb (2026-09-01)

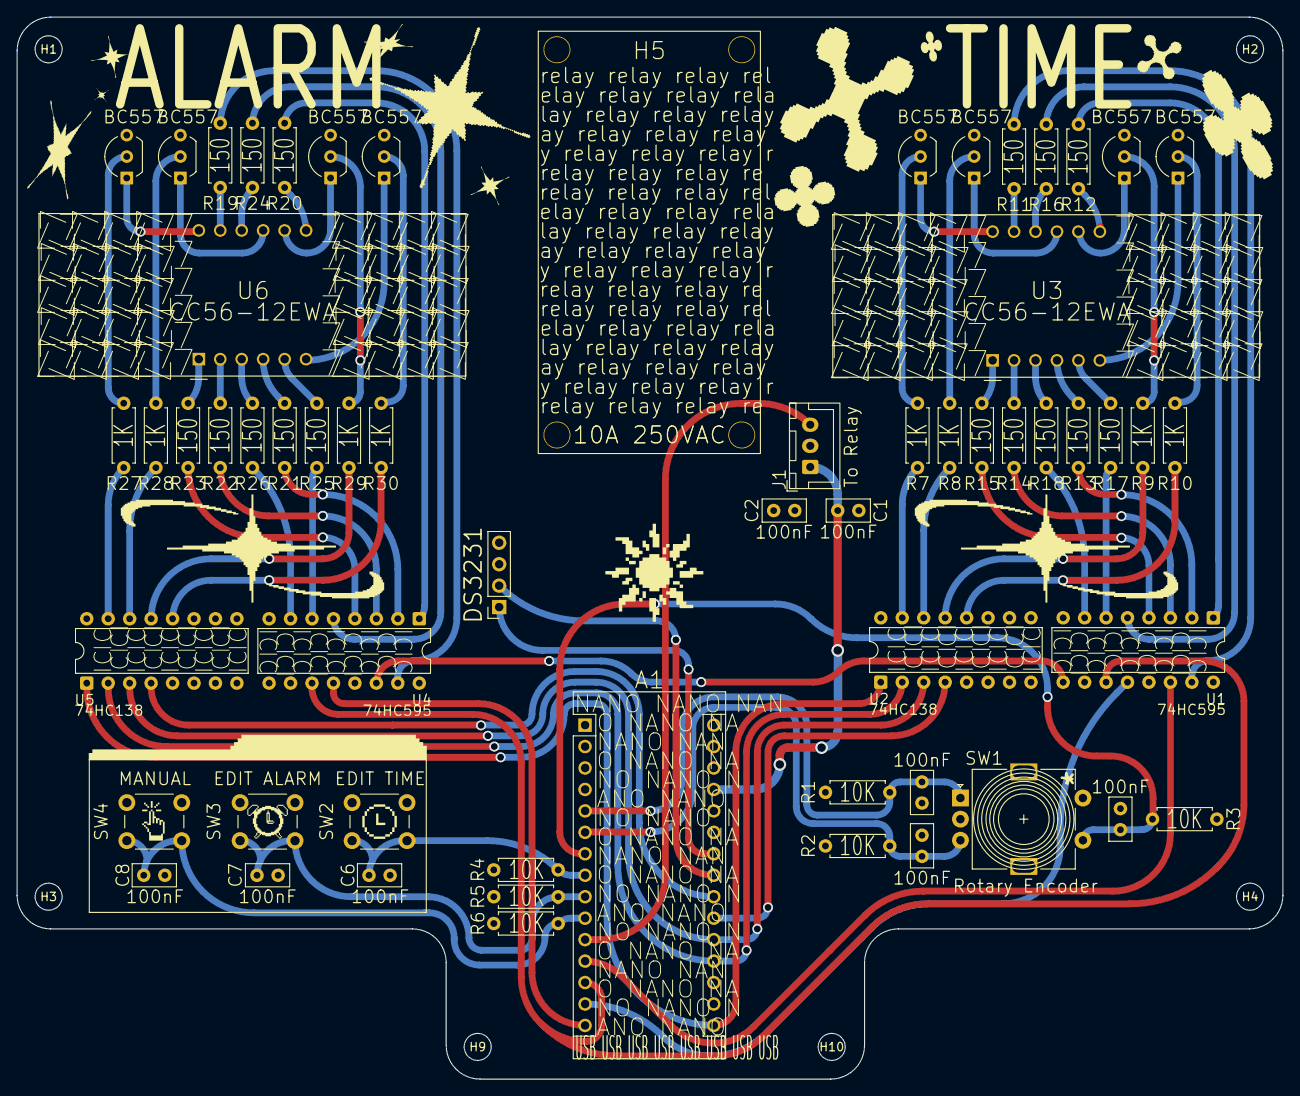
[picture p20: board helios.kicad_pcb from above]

Board: 4 copper layers, 149.9 x 125.7 mm, 66 parts (0 on the bottom side), 78 nets.

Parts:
A1: Arduino_Nano_v3.x; Arduino_Nano
C1, C2, C3, C4, C5, C6, C7, C8: 100nF; C_Disc_D5.0mm_W2.5mm_P2.50mm
H1, H2, H3, H4, H9, H10: MountingHole; MountingHole_3.2mm_M3
H5: MountingHole; Relay_Module_5V_Mounting
J1: To Relay; JST_XH_B3B-XH-A_1x03_P2.50mm_Vertical
J2: DS3231; PinSocket_1x04_P2.54mm_Vertical
Q1, Q2, Q3, Q4, Q5, Q6, Q7, Q8: BC557; TO-92_Inline_Wide
R1, R2, R3, R4, R5, R6: 10K; R_Axial_DIN0207_L6.3mm_D2.5mm_P7.62mm_Horizontal
R7, R8, R9, R10, R27, R28, R29, R30: 1K; R_Axial_DIN0207_L6.3mm_D2.5mm_P7.62mm_Horizontal
R11, R12, R13, R14, R15, R16, R17, R18, R19, R20, R21, R22, R23, R24, R25, R26: 150; R_Axial_DIN0207_L6.3mm_D2.5mm_P7.62mm_Horizontal
SW1: Rotary Encoder; RotaryEncoder_Alps_EC11E-Switch_Vertical_H20mm
SW2, SW3, SW4: SW_Push; SW_PUSH_6mm
U1, U4: 74HC595; DIP-16_W7.62mm
U2, U5: 74HC138; DIP-16_W7.62mm
U3, U6: CC56-12EWA; CA56-12EWA

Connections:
+3V3: A1.17 (3V3), C2.1, J2.3, Q1.3 (E), Q2.3 (E), Q3.3 (E), Q4.3 (E), Q5.3 (E), Q6.3 (E), Q7.3 (E), Q8.3 (E), R1.1, R2.1, R3.1, SW2.2, SW3.2, SW4.2, U1.10 (~SRCLR), U1.16 (VCC), U2.6 (E2), U2.16 (VCC), U4.10 (~SRCLR), U4.16 (VCC), U5.6 (E2), U5.16 (VCC)
+5V: A1.27 (+5V), C1.1, J1.1
/Display_Alarm/DIG5: R27.2, U5.15 (~Y0)
/Display_Alarm/DIG6: R28.2, U5.14 (~Y1)
/Display_Alarm/DIG7: R29.2, U5.13 (~Y2)
/Display_Alarm/DIG8: R30.2, U5.12 (~Y3)
/Display_Alarm/SEG_A: R19.1, U4.15 (QA)
/Display_Alarm/SEG_B: R20.1, U4.1 (QB)
/Display_Alarm/SEG_C: R21.1, U4.2 (QC)
/Display_Alarm/SEG_D: R22.1, U4.3 (QD)
/Display_Alarm/SEG_DP: R26.1, U4.7 (QH)
/Display_Alarm/SEG_E: R23.1, U4.4 (QE)
/Display_Alarm/SEG_F: R24.1, U4.5 (QF)
/Display_Alarm/SEG_G: R25.1, U4.6 (QG)
/Display_Time/DIG1: R7.2, U2.15 (~Y0)
/Display_Time/DIG2: R8.2, U2.14 (~Y1)
/Display_Time/DIG3: R9.2, U2.13 (~Y2)
/Display_Time/DIG4: R10.2, U2.12 (~Y3)
/Display_Time/SEG_A: R11.1, U1.15 (QA)
/Display_Time/SEG_B: R12.1, U1.1 (QB)
/Display_Time/SEG_C: R13.1, U1.2 (QC)
/Display_Time/SEG_D: R14.1, U1.3 (QD)
/Display_Time/SEG_DP: R18.1, U1.7 (QH)
/Display_Time/SEG_E: R15.1, U1.4 (QE)
/Display_Time/SEG_F: R16.1, U1.5 (QF)
/Display_Time/SEG_G: R17.1, U1.6 (QG)
BTN_EDIT_ALARM: A1.9 (D6), C7.1, R5.1, SW3.1
BTN_EDIT_TIME: A1.8 (D5), C6.1, R4.1, SW2.1
BTN_MANUAL: A1.10 (D7), C8.1, R6.1, SW4.1
ENABLE_ALARM: A1.22 (A3), U5.4 (~E0)
ENABLE_TIME: A1.21 (A2), U2.4 (~E0)
ENC_CLK: A1.5 (D2), C4.1, R1.2, SW1.A
ENC_DT: A1.6 (D3), C3.1, R2.2, SW1.B
ENC_SW: A1.7 (D4), C5.1, R3.2, SW1.S1
GND: A1.29 (GND), C1.2, C2.2, C3.2, C4.2, C5.2, C6.2, C7.2, C8.2, J1.2, J2.4, R4.2, R5.2, R6.2, SW1.C, SW1.S2, U1.8 (GND), U1.13 (~OE), U2.5 (~E1), U2.8 (GND), U4.8 (GND), U4.13 (~OE), U5.5 (~E1), U5.8 (GND)
LATCH_ALARM: A1.15 (D12), U4.12 (RCLK)
LATCH_TIME: A1.14 (D11), U1.12 (RCLK)
unnamed: Q1.2 (B), R7.1
unnamed: Q1.1 (C), U3.12 (CC1)
unnamed: Q2.2 (B), R8.1
unnamed: Q2.1 (C), U3.9 (CC2)
unnamed: Q3.2 (B), R9.1
unnamed: Q3.1 (C), U3.8 (CC3)
unnamed: Q4.2 (B), R10.1
unnamed: Q4.1 (C), U3.6 (CC4)
unnamed: Q5.2 (B), R27.1
unnamed: Q5.1 (C), U6.12 (CC1)
unnamed: Q6.2 (B), R28.1
unnamed: Q6.1 (C), U6.9 (CC2)
unnamed: Q7.2 (B), R29.1
unnamed: Q7.1 (C), U6.8 (CC3)
unnamed: Q8.2 (B), R30.1
unnamed: Q8.1 (C), U6.6 (CC4)
unnamed: R18.2, U3.3 (DPX)
unnamed: R11.2, U3.11 (a)
unnamed: R12.2, U3.7 (b)
unnamed: R13.2, U3.4 (c)
unnamed: R14.2, U3.2 (d)
unnamed: R15.2, U3.1 (e)
unnamed: R16.2, U3.10 (f)
unnamed: R17.2, U3.5 (g)
unnamed: R26.2, U6.3 (DPX)
unnamed: R19.2, U6.11 (a)
unnamed: R20.2, U6.7 (b)
unnamed: R21.2, U6.4 (c)
unnamed: R22.2, U6.2 (d)
unnamed: R23.2, U6.1 (e)
unnamed: R24.2, U6.10 (f)
unnamed: R25.2, U6.5 (g)
RELAY_SIG: A1.11 (D8), J1.3
SCL: A1.24 (A5), J2.1
SDA: A1.23 (A4), J2.2
SEL_A: A1.16 (D13), U2.1 (A0), U5.1 (A0)
SEL_B: A1.19 (A0), U2.2 (A1), U5.2 (A1)
SEL_C: A1.20 (A1), U2.3 (A2), U5.3 (A2)
SPI_CLK: A1.13 (D10), U1.11 (SRCLK), U4.11 (SRCLK)
SPI_DATA: A1.12 (D9), U1.14 (SER)
SPI_DATA_OUT: U1.9 (QH'), U4.14 (SER)

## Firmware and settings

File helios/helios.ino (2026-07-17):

#include <Wire.h>
#include <EEPROM.h>

const uint8_t PIN_ENC_CLK      = 2;   // D2
const uint8_t PIN_ENC_DT       = 3;   // D3
const uint8_t PIN_ENC_SW       = 4;   // D4, active LOW (pull-up on board)
const uint8_t PIN_BTN_TIME     = 5;   // D5, active HIGH (pull-down on board)
const uint8_t PIN_BTN_ALARM    = 6;   // D6, active HIGH
const uint8_t PIN_BTN_MANUAL   = 7;   // D7, active HIGH
const uint8_t PIN_RELAY        = 8;   // D8 -> relay module signal
const uint8_t PIN_SPI_DATA     = 9;   // D9  -> U1 SER (chained into U4)
const uint8_t PIN_SPI_CLK      = 10;  // D10 -> both 595 SRCLK
const uint8_t PIN_LATCH_TIME   = 11;  // D11 -> U1 RCLK
const uint8_t PIN_LATCH_ALARM  = 12;  // D12 -> U4 RCLK
const uint8_t PIN_SEL_A        = 13;  // D13 -> 138 A0
const uint8_t PIN_SEL_B        = A0;  //     -> 138 A1
const uint8_t PIN_SEL_C        = A1;  //     -> 138 A2
const uint8_t PIN_EN_TIME      = A2;  // 74HC138 enable, ACTIVE LOW
const uint8_t PIN_EN_ALARM     = A3;  // 74HC138 enable, ACTIVE LOW

#define RELAY_ACTIVE_HIGH   1     // 0 if relay module is active-low 
#define SEGMENTS_ACTIVE_LOW 1     // PNP high-side digit drive -> segments sink (LOW = on)
#define ENCODER_REVERSED    1     // changes encoder's clockwise or counter-clockwise direction
#define ALARM_ON_MINUTES    60UL  // how long the lamp stays on after the alarm fires
#define MUX_INTERVAL_US     2000  // per-digit multiplex period (4 digits -> 125 Hz refresh)
#define BLANK_SETTLE_US     100   // digit-off settle time before lighting (for anti-ghosting)
#define BLINK_PERIOD_MS     200   // edit-mode blink rate
#define DEBOUNCE_MS         50    // press must be stable this long to count
#define EDIT_TIMEOUT_MS     20000 // auto-leave edit mode after this much inactivity
#define DEBUG_SERIAL        0     // FOR DEBUGGING if u wanna test the button functions on the serial monitor

const uint8_t DS3231_ADDR   = 0x68;
const int     EE_MAGIC_ADDR = 0;
const int     EE_ALARM_H    = 1;
const int     EE_ALARM_M    = 2;
const uint8_t EE_MAGIC      = 0xA5;

// 7-segment patterns
const uint8_t DIGIT_FONT[10] = {
  0x3F, 0x06, 0x5B, 0x4F, 0x66, 0x6D, 0x7D, 0x07, 0x7F, 0x6F
};
const uint8_t SEG_BLANK = 0x00;
const uint8_t SEG_DP    = 0x80;

// state
enum Mode : uint8_t {
  MODE_RUN,
  MODE_SET_TIME_H,  MODE_SET_TIME_M,
  MODE_SET_ALARM_H, MODE_SET_ALARM_M
};

Mode     mode         = MODE_RUN;
bool     systemOn     = true;
bool     manualOn     = false;   // manual override: relay forced on + alarm disabled
bool     alarmRinging = false;   // alarm fired, relay on until timeout/cancel
uint32_t alarmStartedMs = 0;
uint32_t lastEditActivityMs = 0; // for the edit-mode inactivity timeout

uint8_t timeH = 0, timeM = 0, timeS = 0;   // current RTC time
uint8_t alarmH = 7, alarmM = 0;            // alarm setpoint
uint8_t editH, editM;                      // scratch values while editing
int8_t  lastAlarmTriggerMin = -1;          // minute-of-day guard, avoids retrigger

// display buffers: segment pattern per digit, index 0 = leftmost
uint8_t timeBuf[4];
uint8_t alarmBuf[4];

// DS3231
uint8_t bcd2dec(uint8_t b) { return (b >> 4) * 10 + (b & 0x0F); }
uint8_t dec2bcd(uint8_t d) { return ((d / 10) << 4) | (d % 10); }

bool rtcReadTime() {
  Wire.beginTransmission(DS3231_ADDR);
  Wire.write(0x00);
  if (Wire.endTransmission() != 0) return false;
  if (Wire.requestFrom(DS3231_ADDR, (uint8_t)3) != 3) return false;
  timeS = bcd2dec(Wire.read() & 0x7F);
  timeM = bcd2dec(Wire.read() & 0x7F);
  timeH = bcd2dec(Wire.read() & 0x3F);   // 24h
  return true;
}

void rtcSetTime(uint8_t h, uint8_t m) {
  Wire.beginTransmission(DS3231_ADDR);
  Wire.write(0x00);
  Wire.write(dec2bcd(0));        // seconds
  Wire.write(dec2bcd(m));
  Wire.write(dec2bcd(h));        // bit6 clear = 24h mode
  Wire.endTransmission();

  // clear the oscillator-stop flag so the time is marked valid
  Wire.beginTransmission(DS3231_ADDR);
  Wire.write(0x0F);
  Wire.endTransmission();
  if (Wire.requestFrom(DS3231_ADDR, (uint8_t)1) == 1) {
    uint8_t status = Wire.read();
    Wire.beginTransmission(DS3231_ADDR);
    Wire.write(0x0F);
    Wire.write(status & ~0x80);
    Wire.endTransmission();
  }
}

// alarm persistence
void loadAlarm() {
  if (EEPROM.read(EE_MAGIC_ADDR) == EE_MAGIC) {
    alarmH = EEPROM.read(EE_ALARM_H) % 24;
    alarmM = EEPROM.read(EE_ALARM_M) % 60;
  }
}

void saveAlarm() {
  EEPROM.update(EE_MAGIC_ADDR, EE_MAGIC);
  EEPROM.update(EE_ALARM_H, alarmH);
  EEPROM.update(EE_ALARM_M, alarmM);
}

// relay
void relayWrite(bool on) {
#if RELAY_ACTIVE_HIGH
  digitalWrite(PIN_RELAY, on ? HIGH : LOW);
#else
  digitalWrite(PIN_RELAY, on ? LOW : HIGH);
#endif
}

void updateRelay() {
  relayWrite(systemOn && (manualOn || alarmRinging));
}

// encoder
int8_t pollEncoder() {
  static uint8_t lastClk = HIGH;
  static uint32_t lastStepMs = 0;
  int8_t step = 0;

  uint8_t clk = digitalRead(PIN_ENC_CLK);
  if (lastClk == HIGH && clk == LOW && (millis() - lastStepMs) > 3) {
    step = digitalRead(PIN_ENC_DT) ? +1 : -1;
#if ENCODER_REVERSED
    step = -step;
#endif
    lastStepMs = millis();
  }
  lastClk = clk;
  return step;
}

// buttons
struct Button {
  uint8_t  pin;
  bool     activeHigh;
  bool     stable;
  bool     lastRaw;
  uint32_t lastChangeMs;
  bool     pressedEvent;
};

Button buttons[] = {
  { PIN_BTN_TIME,   true,  false, false, 0, false },
  { PIN_BTN_ALARM,  true,  false, false, 0, false },
  { PIN_BTN_MANUAL, true,  false, false, 0, false },
  { PIN_ENC_SW,     false, false, false, 0, false },
};
enum { BTN_TIME, BTN_ALARM, BTN_MANUAL, BTN_POWER };

void scanButtons() {
  uint32_t now = millis();
  for (Button &b : buttons) {
    bool raw = digitalRead(b.pin);
    if (!b.activeHigh) raw = !raw;
    if (raw != b.lastRaw) {
      b.lastRaw = raw;
      b.lastChangeMs = now;
    }
    if ((now - b.lastChangeMs) >= DEBOUNCE_MS && raw != b.stable) {
      b.stable = raw;
      if (raw) b.pressedEvent = true;   // rising edge = press
    }
  }
}

bool pressed(uint8_t idx) {
  if (buttons[idx].pressedEvent) {
    buttons[idx].pressedEvent = false;
    return true;
  }
  return false;
}

// display rendering
void renderPair(uint8_t *buf, uint8_t h, uint8_t m, bool hideH, bool hideM) {
  buf[0] = hideH ? SEG_BLANK : DIGIT_FONT[h / 10];
  buf[1] = hideH ? SEG_BLANK : DIGIT_FONT[h % 10];
  buf[2] = hideM ? SEG_BLANK : DIGIT_FONT[m / 10];
  buf[3] = hideM ? SEG_BLANK : DIGIT_FONT[m % 10];
}

void renderDisplays() {
  bool blinkOff = (millis() / BLINK_PERIOD_MS) & 1;

  // TIME
  if (mode == MODE_SET_TIME_H || mode == MODE_SET_TIME_M) {
    renderPair(timeBuf, editH, editM,
               mode == MODE_SET_TIME_H && blinkOff,
               mode == MODE_SET_TIME_M && blinkOff);
  } else {
    renderPair(timeBuf, timeH, timeM, false, false);
    if (timeS & 1) timeBuf[1] |= SEG_DP;   // 1 Hz dot blink
  }

  // ALARM
  if (mode == MODE_SET_ALARM_H || mode == MODE_SET_ALARM_M) {
    renderPair(alarmBuf, editH, editM,
               mode == MODE_SET_ALARM_H && blinkOff,
               mode == MODE_SET_ALARM_M && blinkOff);
  } else {
    renderPair(alarmBuf, alarmH, alarmM, false, false);
  }
  alarmBuf[1] |= SEG_DP;                     // hh.mm separator, always on
  if (!manualOn) alarmBuf[3] |= SEG_DP;      // armed indicator
}

// shift one digit's pattern into both 595s and latch
void shiftBoth(uint8_t alarmByte, uint8_t timeByte) {
#if SEGMENTS_ACTIVE_LOW
  alarmByte = ~alarmByte;
  timeByte  = ~timeByte;
#endif
  shiftOut(PIN_SPI_DATA, PIN_SPI_CLK, MSBFIRST, alarmByte);
  shiftOut(PIN_SPI_DATA, PIN_SPI_CLK, MSBFIRST, timeByte);
  digitalWrite(PIN_LATCH_TIME, HIGH);
  digitalWrite(PIN_LATCH_ALARM, HIGH);
  digitalWrite(PIN_LATCH_TIME, LOW);
  digitalWrite(PIN_LATCH_ALARM, LOW);
}

void muxStep() {
  static uint8_t phase = 0;

  digitalWrite(PIN_EN_TIME,  HIGH);
  digitalWrite(PIN_EN_ALARM, HIGH);

  shiftBoth(SEG_BLANK, SEG_BLANK);          // drain the segment lines while blanked

  digitalWrite(PIN_SEL_A, phase & 1);
  digitalWrite(PIN_SEL_B, (phase >> 1) & 1);
  digitalWrite(PIN_SEL_C, LOW);

  shiftBoth(alarmBuf[phase], timeBuf[phase]);

  if (systemOn) {
    delayMicroseconds(BLANK_SETTLE_US);     // let PNPs/segment lines settle first
    digitalWrite(PIN_EN_TIME,  LOW);
    digitalWrite(PIN_EN_ALARM, LOW);
  }

  phase = (phase + 1) & 3;
}

// alarm logic
void checkAlarm() {
  int16_t nowMin = timeH * 60 + timeM;

  if (systemOn && !manualOn && mode == MODE_RUN &&
      timeH == alarmH && timeM == alarmM && nowMin != lastAlarmTriggerMin) {
    lastAlarmTriggerMin = nowMin;
    alarmRinging = true;
    alarmStartedMs = millis();
  }
  if (nowMin != lastAlarmTriggerMin) lastAlarmTriggerMin = -1;

  if (alarmRinging && (millis() - alarmStartedMs) >= ALARM_ON_MINUTES * 60000UL) {
    alarmRinging = false;
  }
}

// input handling / state machine
bool inEditMode() { return mode != MODE_RUN; }

void applyEncoderToEdit(int8_t d) {
  if (d == 0) return;
  lastEditActivityMs = millis();
  switch (mode) {
    case MODE_SET_TIME_H:
    case MODE_SET_ALARM_H:
      editH = (uint8_t)((editH + 24 + (d % 24)) % 24);
      break;
    case MODE_SET_TIME_M:
    case MODE_SET_ALARM_M:
      editM = (uint8_t)((editM + 60 + (d % 60)) % 60);
      break;
    default:
      break;
  }
}

void handleInputs() {
  int8_t enc = pollEncoder();

  // power toggle (encoder push)
  // ignored while editing so an accidental knob press mid-edit can't switch the whole system off
  if (pressed(BTN_POWER) && !inEditMode()) {
#if DEBUG_SERIAL
    Serial.println(F("BTN_POWER (enc)"));
#endif
    systemOn = !systemOn;
    if (!systemOn) {
      mode = MODE_RUN;
      manualOn = false;
      alarmRinging = false;
    }
  }

  if (!systemOn) return;

  if (pressed(BTN_TIME)) {
#if DEBUG_SERIAL
    Serial.println(F("BTN_TIME (D5)"));
#endif
    lastEditActivityMs = millis();
    switch (mode) {
      case MODE_RUN:        editH = timeH; editM = timeM; mode = MODE_SET_TIME_H; break;
      case MODE_SET_TIME_H: mode = MODE_SET_TIME_M; break;
      case MODE_SET_TIME_M:
        rtcSetTime(editH, editM);
        timeH = editH; timeM = editM; timeS = 0;
        mode = MODE_RUN;
        break;
      default: break;   // ignore while editing the alarm
    }
  }

  if (pressed(BTN_ALARM)) {
#if DEBUG_SERIAL
    Serial.println(F("BTN_ALARM (D6)"));
#endif
    lastEditActivityMs = millis();
    switch (mode) {
      case MODE_RUN:         editH = alarmH; editM = alarmM; mode = MODE_SET_ALARM_H; break;
      case MODE_SET_ALARM_H: mode = MODE_SET_ALARM_M; break;
      case MODE_SET_ALARM_M:
        alarmH = editH; alarmM = editM;
        saveAlarm();
        mode = MODE_RUN;
        break;
      default: break;   // ignore while editing the time
    }
  }

  if (pressed(BTN_MANUAL)) {
#if DEBUG_SERIAL
    Serial.println(F("BTN_MANUAL (D7)"));
#endif
    if (alarmRinging) {
      alarmRinging = false;        // first press just cancels the alarm
    } else {
      manualOn = !manualOn;        // override on = relay on, alarm disabled
      if (manualOn) alarmRinging = false;
    }
  }

  // encoder only acts in edit modes
  if (inEditMode()) {
    applyEncoderToEdit(enc);
    if (millis() - lastEditActivityMs > EDIT_TIMEOUT_MS) mode = MODE_RUN;
  }
}

// setup
void setup() {
#if DEBUG_SERIAL
  Serial.begin(115200);
  Serial.println(F("HELIOS debug"));
#endif

  pinMode(PIN_ENC_CLK,     INPUT);
  pinMode(PIN_ENC_DT,      INPUT);
  pinMode(PIN_ENC_SW,      INPUT);
  pinMode(PIN_BTN_TIME,    INPUT);
  pinMode(PIN_BTN_ALARM,   INPUT);
  pinMode(PIN_BTN_MANUAL,  INPUT);

  pinMode(PIN_RELAY,       OUTPUT);
  pinMode(PIN_SPI_DATA,    OUTPUT);
  pinMode(PIN_SPI_CLK,     OUTPUT);
  pinMode(PIN_LATCH_TIME,  OUTPUT);
  pinMode(PIN_LATCH_ALARM, OUTPUT);
  pinMode(PIN_SEL_A,       OUTPUT);
  pinMode(PIN_SEL_B,       OUTPUT);
  pinMode(PIN_SEL_C,       OUTPUT);
  pinMode(PIN_EN_TIME,     OUTPUT);
  pinMode(PIN_EN_ALARM,    OUTPUT);

  relayWrite(false);
  digitalWrite(PIN_EN_TIME,  HIGH);   // displays off until first mux step
  digitalWrite(PIN_EN_ALARM, HIGH);
  digitalWrite(PIN_LATCH_TIME,  LOW);
  digitalWrite(PIN_LATCH_ALARM, LOW);

  Wire.begin();
  loadAlarm();
  rtcReadTime();
}

// loop
void loop() {
  static uint32_t lastMuxUs  = 0;
  static uint32_t lastRtcMs  = 0;

  uint32_t nowUs = micros();
  if (nowUs - lastMuxUs >= MUX_INTERVAL_US) {
    lastMuxUs = nowUs;
    muxStep();
  }

  if (millis() - lastRtcMs >= 200) {
    lastRtcMs = millis();
    rtcReadTime();
    checkAlarm();
  }

  scanButtons();
  handleInputs();
  renderDisplays();
  updateRelay();
}

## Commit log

2026-07-01 added schematic
    [display_alarm.kicad_sch, display_time.kicad_sch, inputs.kicad_sch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]
2026-07-05 finish PCB + rename project
    [display_alarm.kicad_sch, display_time.kicad_sch, helios.kicad_pcb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]
2026-07-06 small PCB fixes + print
    [helios.kicad_pcb]
2026-07-08 added 4-layer design
    [display_alarm.kicad_sch, display_time.kicad_sch, helios.kicad_pcb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]
2026-07-17 added MCU code + documentation
    [display_alarm.kicad_sch, display_time.kicad_sch, helios.kicad_pcb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]
2026-07-17 PCB CC->CA footprint fix + display blink rate adjustment
    [helios.kicad_pcb]
2026-09-01 update 4layer board
    [helios.kicad_pcb]
2026-09-01 more pixel assets for the 4layer board
    [helios.kicad_pcb]
